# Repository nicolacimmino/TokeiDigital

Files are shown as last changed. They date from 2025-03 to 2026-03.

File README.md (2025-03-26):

# TokeiDigital

TokeiDigital [to̞ke̞ːdigital] is a line of clocks for geeks, nerds, and makers that come in a kit to assemble. The clock faces are unconventional and, true to the spirit of this project, always abound with colorful, blinking lights. These clocks are for you if:

* You believe a UART is a cool interface to setup a clock.
* You believe setting registers HEX values in a terminal is a good way to change LED colors and tweak settings.
* You believe a clock that just shows time with two hands is boring.



All models come with full schematics, PBCs, source code and all tools needed to program the clock. The project is OSHWA certified (PL000019).

Additionally you can buy them as kits ready to assemble on Tindie: https://www.tindie.com/stores/nicola_cimmino/

### Models

|Model|Description|Time|Date|DST|LEDs|Movement|
|-----|---|---|----|---|----|----|
| [TD-FBUH01](board/TD-FBUH01) |Reproduction of the iconic Berlin Uhr.|X||X*1|36 RGB|TD-M5037|
| [TD-FDCF01](board/TD-FDCF01) |60 LEDs display time encoded as DCF77 bitstream.|X|X|X|60 RGB|TD-M5037|

<sub>*1) How can DST work if there's no date? The movment, internally, tracks the date, but the clock face doesn't have LEDs to show it. For DST Auto to work correctly you will need to set the date using the serial interface.</sub>

### Movements

|Model|Description|UART|Backup<br>Battery|W (mm)|H (mm)|
|-----|---|---|----|---|----|
| [TD-M5037](board/TD-M5037)|Basic but powerful movement.|X|CR2032|50|37|

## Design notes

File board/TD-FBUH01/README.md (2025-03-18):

## TD-FBUH01

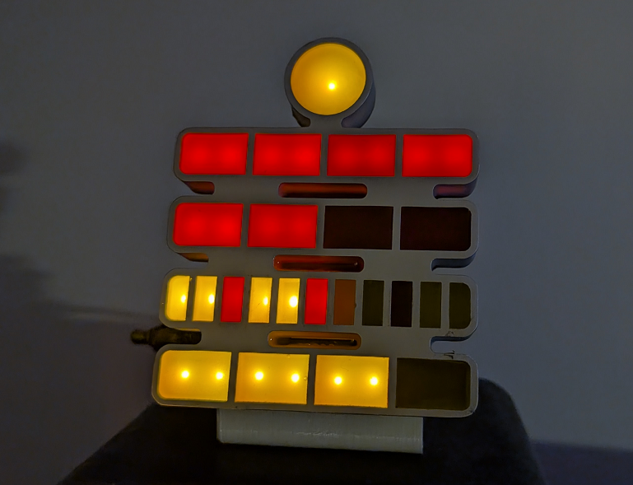
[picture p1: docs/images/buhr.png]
BerlinUhr


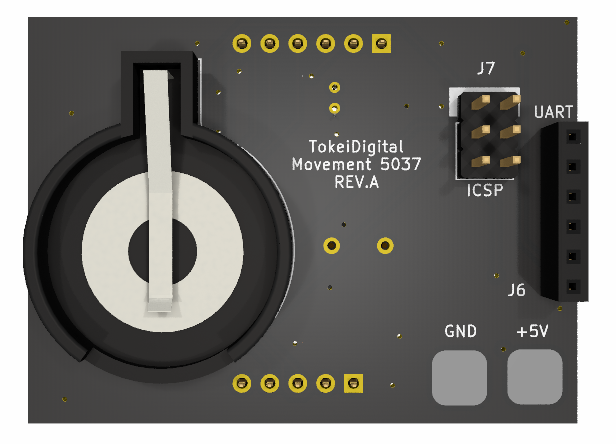
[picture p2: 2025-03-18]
docs/images/TD-M5037-pinout-back.png

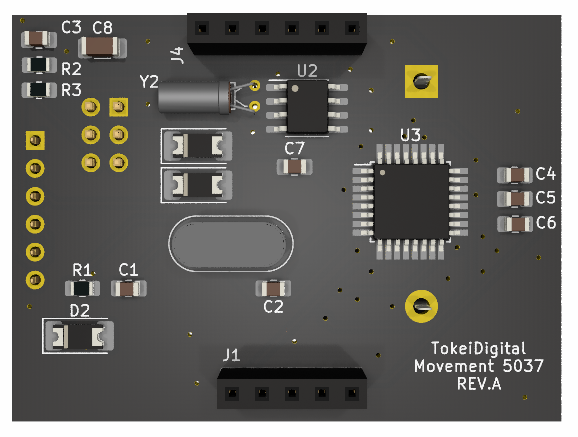
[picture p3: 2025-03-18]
docs/images/TD-M5037-pinout.png

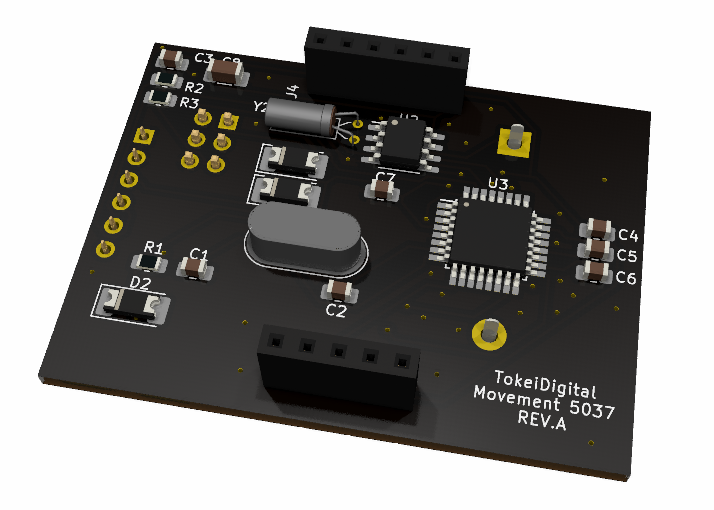
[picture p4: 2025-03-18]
docs/images/TD-M5037.png

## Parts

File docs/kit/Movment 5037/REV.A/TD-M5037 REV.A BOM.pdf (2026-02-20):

## Movement 5037 - REV.A BOM

Reference | Qty | Value
BT1 | 1 | CR3032 Holder
C1, C2 | 2 | 22p (0805)
C3, C4, C5, C6, C7 | 5 | 100nF (0805)
C8 | 1 | 10uF (1206)
D1, D2, D3 | 3 | 1N5817 (2010)
J1 | 1 | Pin 1x5 Vertical Female
J4, J6 | 2 | Pin 1x6 Vertical Female
R1, R2, R3 | 3 | 10K (0805)
U2 | 1 | DS1307 (SOIC-8)
U3 | 1 | ATmega328PB-QFP
Y1 | 1 | 16MHz (TH)
Y2 | 1 | 32.768KHz (TH)

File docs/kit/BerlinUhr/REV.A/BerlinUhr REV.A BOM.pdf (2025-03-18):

## BerlinUhr - REV.A

Reference | Qty | Value
D1..D36 | 36 | WS2812 5mm
SW1, SW2, SW3 | 3 | SW_Push
J1 | 1 | Pin 1x5 Vertical Female
J2 | 1 | Pin 1x6 Vertical Female

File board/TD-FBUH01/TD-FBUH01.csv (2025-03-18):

# | Reference | Qty | Value | Footprint | DNP
1 | D1, D2, D3, D4, D5, D6, D7, D8, D9, D10, D11, D12, D13, D14, D15, D16, D17, D18, D19, D20, D21, D22, D23, D24, D25, D26, D27, D28, D29, D30, D31, D32, D33, D34, D35, D36 | 36 | ~ | ClockIt:WS2812-5MM
2 | SW1, SW2, SW3 | 3 | SW_Push | ClockIt:Tactile SW SMD
3 | U1 | 1 | ~ | ClockIt:Movement5037 TH

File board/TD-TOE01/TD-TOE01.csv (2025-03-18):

# | Reference | Qty | Value | Footprint | DNP
1 | BT1 | 1 | CR3032 Holder | ClockIt:CR2032 Holder
2 | C1, C2 | 2 | 22p | ClockIt:C_0805
3 | C3, C4, C5, C6, C7 | 5 | 100nF | ClockIt:C_0805
4 | C8 | 1 | 10uF | ClockIt:C_1206
5 | D1, D2, D3 | 3 | 1N5817 | ClockIt:D_2010
6 | J1 | 1 | Pin 1x5 | ClockIt:PIN 1x05
7 | J4, J6 | 2 | Pin 1x6 | ClockIt:PIN 1x06
8 | J5, J8 | 2 | PowerPad | ClockIt:Power Pin
9 | J7 | 1 | AVR-ISP | ClockIt:PIN 2x03
10 | R1, R2, R3 | 3 | 10K | ClockIt:R_0805
11 | U2 | 1 | DS1307 | ClockIt:SOIC-8
12 | U3 | 1 | ATmega328PB-QFP | ClockIt:TQFP-32
13 | Y1 | 1 | 16MHz | ClockIt:Crystal Vertical
14 | Y2 | 1 | 32.768KHz | ClockIt:Crystal Horizontal

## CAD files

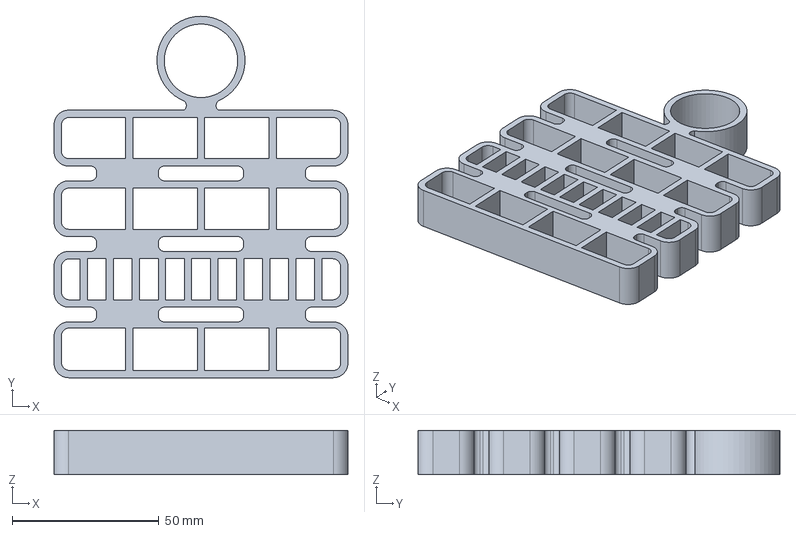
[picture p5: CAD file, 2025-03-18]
3d/TD-FBUH01/TD-FBUH01.FCStd
100.0 x 123.0 x 15.0 mm

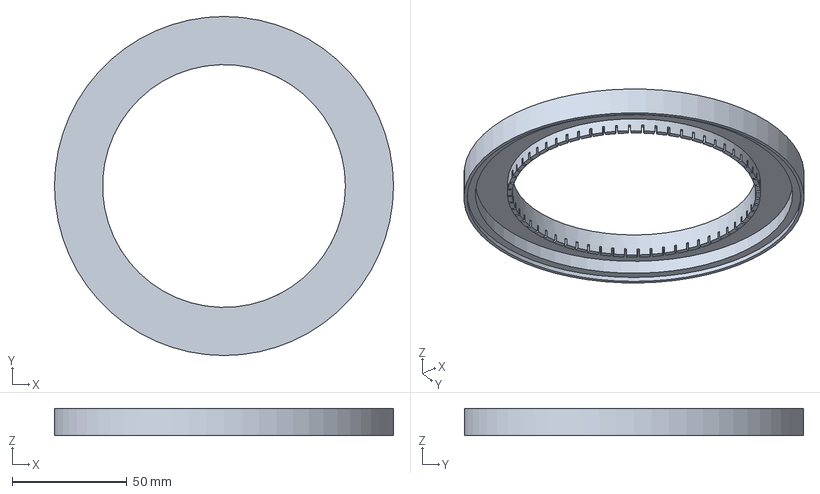
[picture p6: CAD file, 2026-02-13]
3d/TD-FDCF01/FaceDCF77_v3.FCStd
148.0 x 148.0 x 12.0 mm

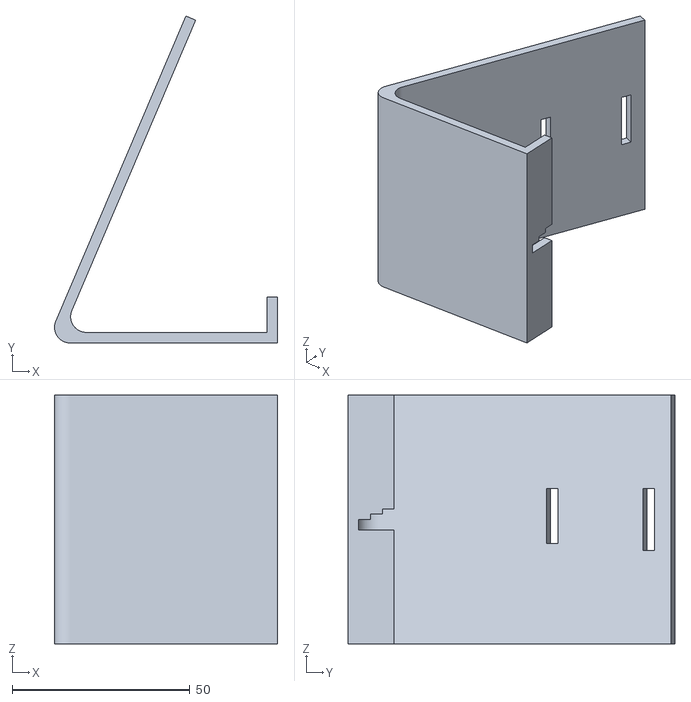
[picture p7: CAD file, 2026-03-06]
3d/TD-M5037A-SM/TD-M5037A-SM-Body.stl
62.7 x 92.0 x 70.0

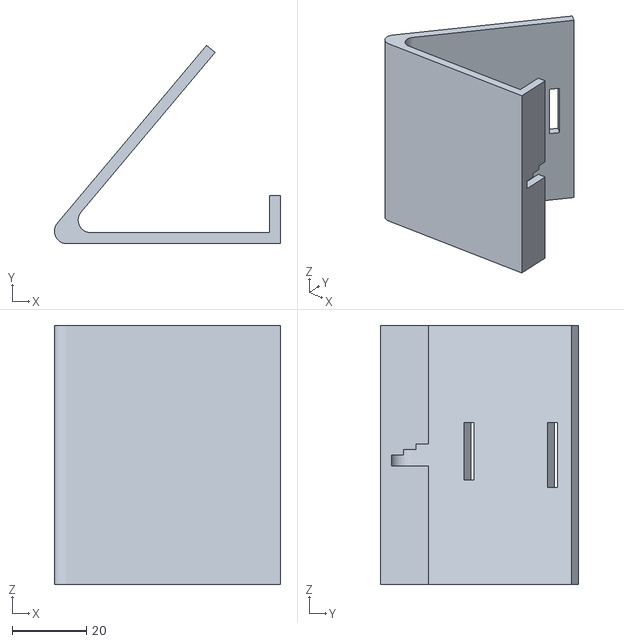
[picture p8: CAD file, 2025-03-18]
3d/TD-M5037A-SS/TD-M5037A-SS-Body.stl
61.1 x 53.6 x 70.0

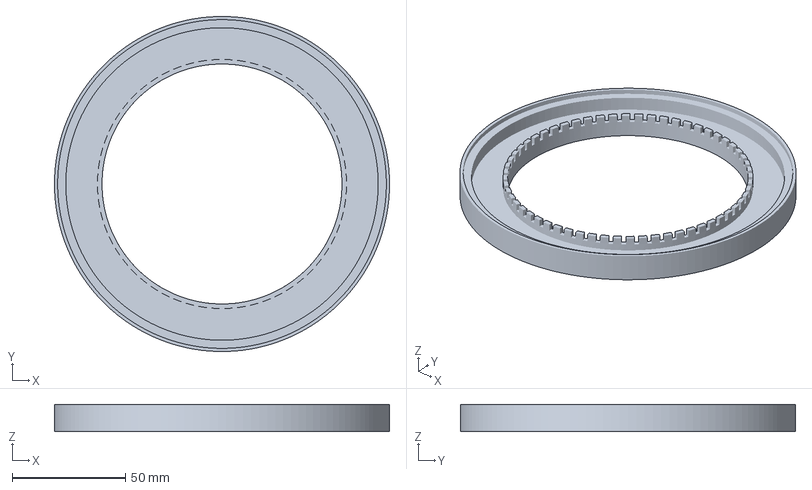
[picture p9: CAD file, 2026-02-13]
3d/TD-FDCF01/FaceDCF77_v3-Body.3mf
148.0 x 148.0 x 12.0 mm

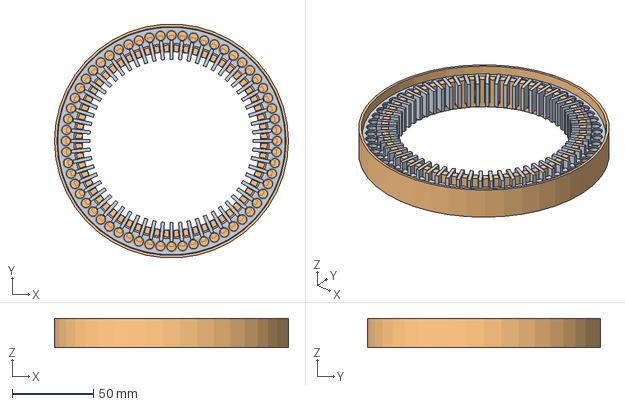
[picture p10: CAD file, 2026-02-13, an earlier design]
3d/TD-FDCF01/FaceDCF77_v2.FCStd
144.0 x 143.6 x 18.0 mm
LightGuide
Cover

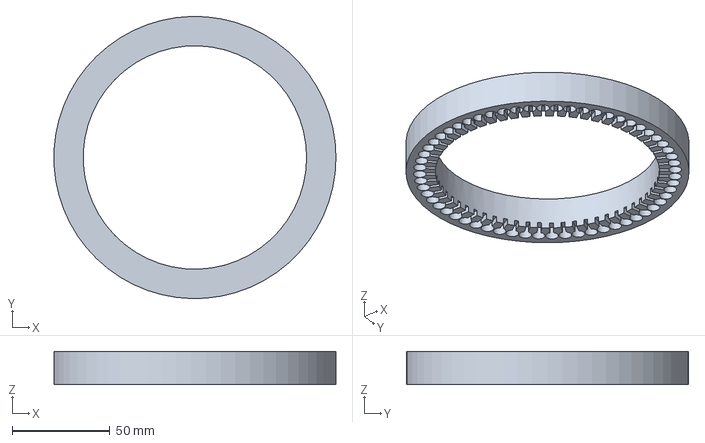
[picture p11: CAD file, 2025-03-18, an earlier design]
3d/TD-FDCF01/FaceDCF77.FCStd
143.9 x 143.9 x 17.0 mm

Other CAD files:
3d/TD-M5037A-SM/TD-M5037A-SM.FCStd
3d/TD-M5037A-SS/TD-M5037A-SS.FCStd
3d/TD-FDCF01/FaceDCF77_v3-Body.stl

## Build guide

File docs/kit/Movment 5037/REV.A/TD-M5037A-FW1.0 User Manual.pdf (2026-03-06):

# TD-M5037A-FW1.0

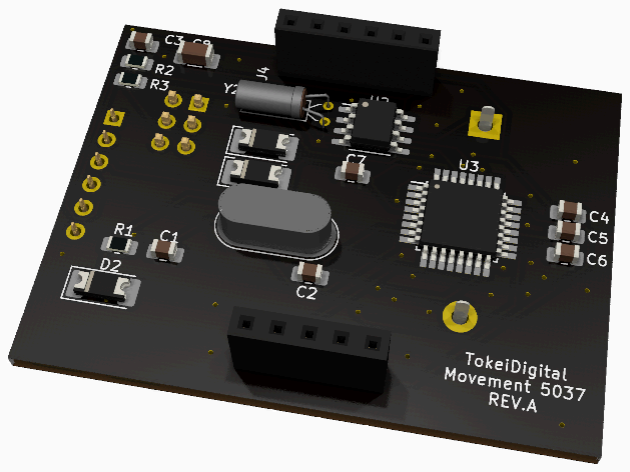
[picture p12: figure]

# User Manual

TD-M5037A-FW1.0 User Manual

# General

## Features

The Tokei Digital TD-M5037 is a general purpose clock module that can be used as the base for designing clocks with different faces. It provides a RTC, with a backup battery, that can keep track of the current date and time even when the clock is not powered.

The module has a UART interface, allowing the user to set the time via a command interface and to tweak the configuration of both the module and the clock face.

Additionally the module provides several GPIO pins to both control a clock face and receive input from buttons placed on the clock face. These buttons allow the user to set the time in a more traditional way.

The module can also automatically switch to DST and back (EU rules only in FW1.0, for other territories DST can be set manually through the UART or simply ignored and time adjusted manually on the change date).

If you purchased the TD-M5037A as a kit to assemble see the “Assembling the Board” chapter for assembly instructions.

## Connections

Two female pin headers, protruding on the top side (opposite the battery) provide the mating interface to the clock face. The headers have 5 and 6 pins respectively to serve as a guide for the correct orientation of the module when plugging it on the face. These pins provide power to the clock face, digital data to control it, and bring into the module the lines from the three A,B,C buttons.

The choice to have the buttons on the clock face instead of the module was made to provide more flexibility in the design of the final clock, leaving freedom on the placement of the buttons on the face. In the same way, the power input to this module is made of two large pads where to solder the power supply. This allows for greater flexibility in the placement of eventual battery holders or external power connectors. An onboard USB connector would have instead limited the options and, depending on the clock face shape and orientation, could have resulted in the USB connector sitting in a non suitable location.

On the side opposite the headers is a holder for a CR2032 battery. If the battery is not installed time will be lost every time the power is lost. It’s strongly recommended to use a backup battery, however normal operation is possible without.

On the same side is also an ICSP (In Circuit Serial Programmer) interface that allows to flash a new version of the firmware or to flash an Arduino bootloader. If you received the module as part of a clock kit the firmware has already been flashed with the correct one for the face you selected and you will not need this interface.

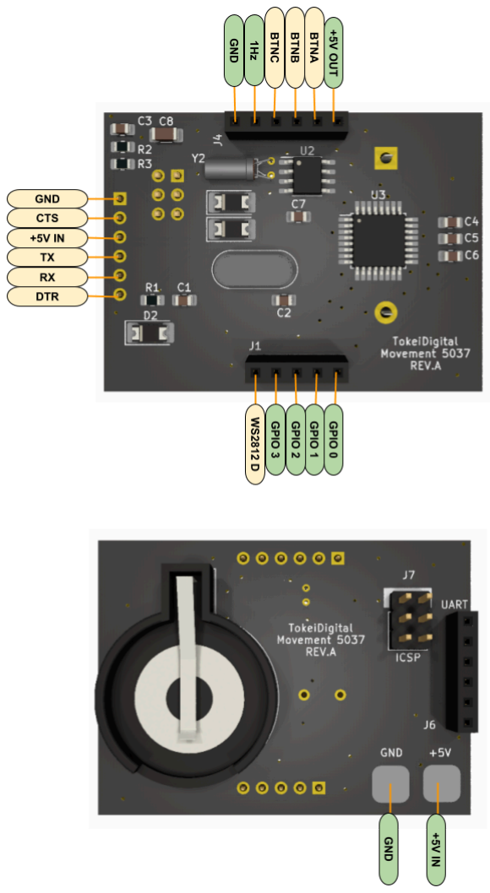
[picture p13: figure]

The table below details all the pins and their function.

+5V OUT | Power supply output for the clock face. Max available current for the face is 100mA.
BTNA,B,C | Input pins for Buttons A,B,C. The module has internal pull-ups and expects the buttons to be pulling towards ground when pressed. These buttons allow you to do things like setting the date/time.
1Hz | 1Hz Square Wave output. This is an open collector output.
GND | Common ground connection for powering the clock face.
CTS/TX/RX/DTR | UART interface. Allows to configure the clock through a serial interface. Also, if the module is flashed with the Arduino bootloader, sketches can be uploaded through this interface.
GPIO0,1,2,3 | General input/output pins that can be used by the clock face.
WS2812D | Dedicated output pin for clocks using WS2812 LEDs. If your clock face doesn’t use such LEDs this pin can be used as general IO.
+5V IN | Power Supply pad. There is polarity protection on board but no voltage protection. Ensure your power supply is stable and doesn’t exceed 5V. It needs to be able to supply enough current for the clock face (the movement consumption is few mA only).

## Setting Date and Time

Time set mode is entered with a long press on the A button. The first settable value (usually the hours) will start to flash on the clock face. Usually the clock will also indicate in some other way that it entered the time set mode, for instance flashing an LED or changing its color. For details see your specific clock face user manual.

NOTE: depending on how your clock displays time, if the current value being set is zero you might not see anything flashing (e.g. in a binary clock). Press B or C once so the value is increased/decreased.

Once time set mode is entered use B and C to increase/decrease the value being set respectively. To move to the next value (e.g. minutes) just press once A. Depending on the abilities of your clock, you will cycle through all the values that can be set and return to the hours.

Once you are done setting the time, long press again A to exit time set mode.

Hint: to achieve a second-accurate setting, set the clock to the next minute. Then wait in time set mode until your reference clock shows :59 seconds, only at this point long press on A to exit time set mode. This works because, upon exciting time set mode, the clock always starts from second :00.

## Display Test Mode

It’s possible to enter test mode for your clock by long pressing on the C button. In this mode your clock will light all LEDs regardless of current time. This can be useful to ensure all LEDs are functioning and to test your power supply and ensure it can provide enough current. Long press again C to exit test mode.

# Assembling the Board

## Packing List

Before proceeding with the assembly of the components on the board, double check the packing list to make sure you have received all components and that everything is in good order.

Bag | Content
A | 2 x 22p (0805)
B | 5 x 100nF (0805)
C | 1 x 10uF (1206)
D | 1 x 1N5817 (2010)
E | 3 x 10K (0805)
F | 1 x ATmega328 (QFP-32) 1 x DS1307 (SOIC-8)
G | 1 x 16MHz Crystal 1 x 32.768KHz Crystal 1 x CR3032 Holder 1 x Pin 1x5 Vertical Female 1 x Pin 1x6 Vertical Female
| 1 x PCB TD-M5037A REV.A

## Top Assembly

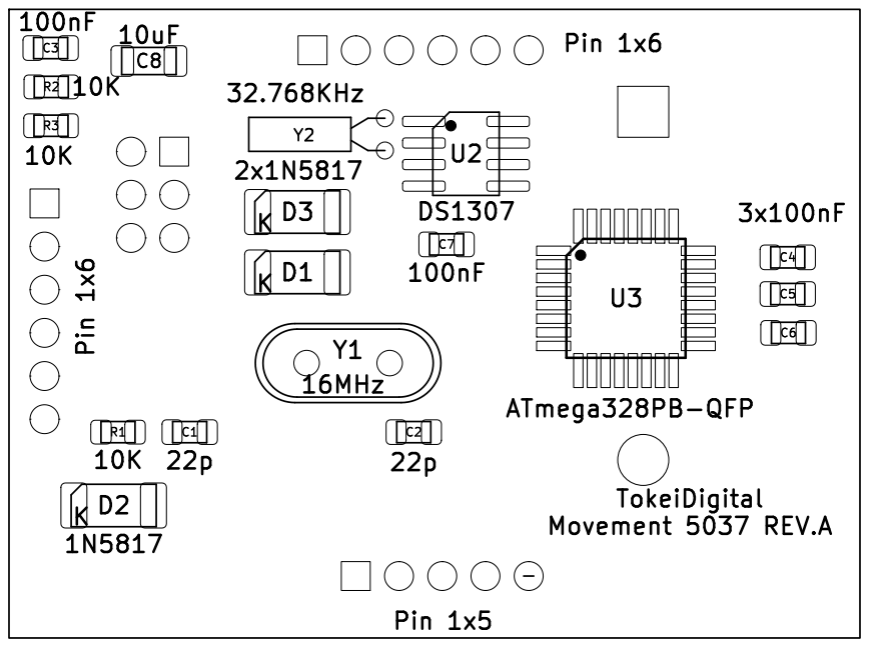
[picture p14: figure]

All components, with the exception of the battery holder, are assembled on the top part of the board. Depending on the tools you have available and your preference, you can use solder paste and position all the SMDs first to then reflow the board or just assemble the SMDs by hand. If you choose to assemble by hand make sure you have a very fine solder tip and very fine (0.2mm) tin. Pay attention to the orientation of diodes (the K marking on the image above corresponds to the grey band on the body of the component). Also the two chips need to be aligned with the dot on the body matching the image above. Assemble the crystals next and, finally, solder the pin headers on this same side of the board.

## Bottom Assembly

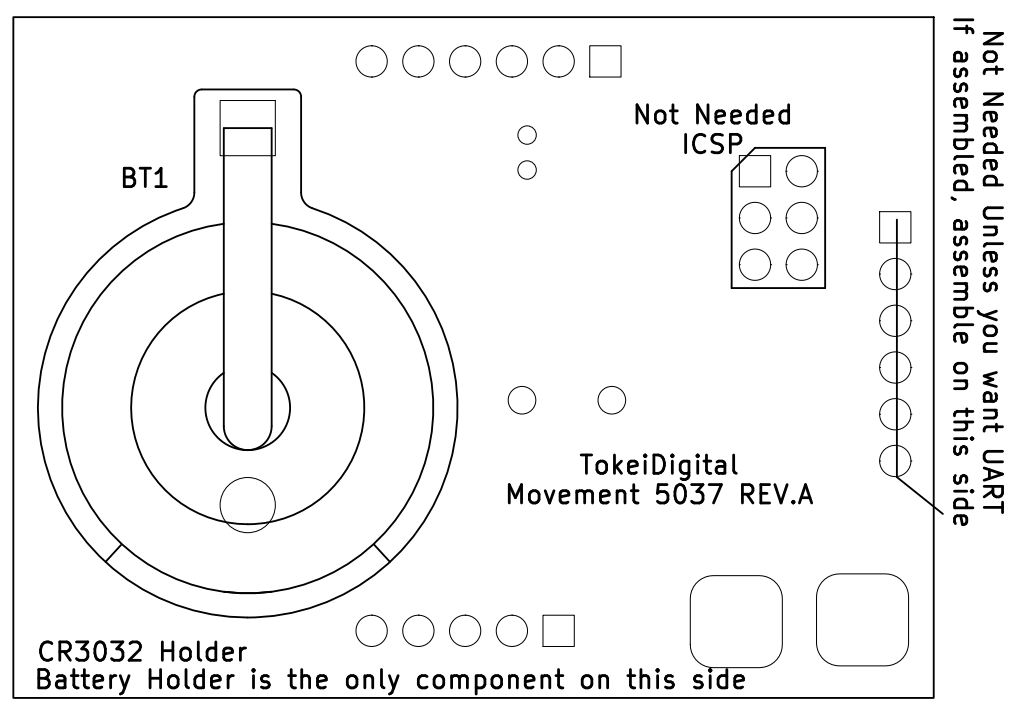
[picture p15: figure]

Flip the board and install the battery holder. For clock operation no other components are needed. If you are planning to use the UART you can install a 6 pin header on the pads labelled UART on the board. The choice of the type of pin header (male/female, 90 degrees etc.) depends on the type of USB-UART adapter board you have, whether you plan to encase the clock or not. The square pin is GND.

Also the ICSP connector (2x3 pins) is not needed unless you want to replace the firmware of the module, for instance to flash your own code for the clock face, an Arduino bootloader or an updated version of the firmware. Again, the type of pins depends on your programmer cable, though usually these are male pins.

Finally a power source needs to be soldered to the GND and +5 pads. Once more, the type of cable, battery holder or perhaps USB connector adapter board depends on how you plan to display and eventually encase your clock. For this reason the board was not designed with a USB onboard connector but just with the pads.

# Advanced

## UART

The module exposes a UART interface that allows the user to configure the module, including setting time, DST and, depending on the clock face, color of the LEDs and other face features.

## Physical Interface

The only pins needed to control the UART are TX, RX, and GND. The other standard serial port lines are used only by the Arduino bootloader if you choose to flash it.

The UART operates at 9600 BAUD, 8 bits, 1 stop bit (no parity).

The terminal should be configured for CR+LF line ending.

## Commands

Press enter once you connect to get a list of all the available commands and a banner reporting the current hardware and firmware versions. If you don’t receive any response, double check the connections and make sure the serial port parameters are set correctly.

TOKEI DIGITAL MOVEMENT 5037
VER: V1.0
FACE DRIVER: BUHR
H | HELP
N | PRINT NOW
R [START] [END] DUMP REGISTERS
S [START] | SET REGISTERS
T H:M WD D-M-Y | SET DATE/TIME
X | EXIT
OK

When you connect you might start to receive a burst of messages every second. These report the current date/time and other information. They can be set on/off by setting the relevant register (see next section). If the messages are coming they will stop once you press enter and will not resume until you exit interactive mode by giving the “X” command.

Print Current Time (N)
Send the “N” (now) command and press enter. The module will respond with the current date and time:

19:14 2 11-02-25
OK

The string is in the format:

HH:MM dayOfWeek day-month-year

Day of week is 1-7, with 1 indicating Monday.

Set Current Time (T)
Send the “T” (time) command followed by a space and the date and time you want to set. Use the same format returned by the N command.

T 19:14 2 11-02-25
OK

Dump Registers (R)
Send the “R” (read registers) command and press enter. The module will respond with a dump of all registers. Optionally you can specify a start and end (hex values) to limit the output.

R 0B 14
0008 | 00.00.00.00.00
0010 00.00.00.00.00.
OK

R
0000 00.00.00.01.00.00.00.00 0008 00.00.00.00.00.00.00.00 0010 00.00.00.00.00.00.00.00 0018 00.00.00.00.00.00.00.00 0020 00.00.00.00.00.00.00.00 0028 00.00.00.00.00.00.00.00 0030 00.00.00.00.00.00.00.00 0038 00.00.00.00.00.00.00.00 0040 00.00.00.05.00.00.05.05 0048 00.04.02.00.00.00.05.05 0050 00.05.02.04.04.01.06.02 0058 01.05.00.02.02.02.30.30 0060 30.00.00.00.00.00.00.00 0068 00.00.00.00.00.00.00.00 0070 00.00.00.00.00.00.00.00
0078 00.00.00.00.00.00.00.00
OK

For the meaning of each register see the next section which details the movement registers. See also your clock guide for face specific registers.

Set Registers (S)
Send the “S” (set registers) command followed by a space and the address (hexadecimal) of the first register you want to set. This command is interactive and will print the address and current value of the register.
You can now enter a new value, in hexadecimal and press enter. If you don’t want to change that register value you can just press enter to move to the next. Once you are done editing press X and enter to exit the command.

S 7B
007B 00 .
007C 01 .01
007D 02 .02
007E 00 .X
OK

Exit Interactive Mode (X)
Once you are done you can send the X command and press enter to exit the interactive mode. If the serial output is enabled (see register 0x03) the notifications will resume.

## Registers Map

0x00 - 0x3F Movement Registers | 0x00 | DST. | 0=AUTO, 1=OFF, 2=ON
| 0x01 | Reserved for future use.
| 0x02 | Reserved for future use.
| 0x03 | Serial output protocol. | 0=OFF, 1=V1
0x40 - 0x7F Face Registers | See face manual for usage.

0x00 If set to 0 DST AUTO is enabled and the clock will transition automatically in and out of summer time on the correct date. Currently the module supports the EU rules only. If you live in a different territory you can set manually DST on/off on the change date and the time will adjust. You can also leave DST OFF and change the time manually on the change day.

0x03 Controls the serial output protocol. When enabled (set to 1 for Version 1) the module will send out messages at one second interval. The messages continue indefinitely until you press enter, at that point they stop to allow usage of the interactive interface. The messages will resume exiting interactive mode with the X command. Messages look as follows:

$V1!INFO0,V1.0,DCF77
$V1!DATE,11-02-2025
$V1!TIME,19:37:29
$V1!DOW,2
$V1!DST,OFF,AUTO

Each message starts with $ followed by the protocol version. Following are comma separated tokens. The first indicating the message type and the others, in variable amount, are the parameters. Each message ends with a CR+LF.

$V1!INFO0 reports firmware version and face type.

$V1!DATE reports the current date in dd-mm-yyyy format.

$V1!TIME reports the current time in HH:MM:SS format.

$V1!DOW reports the current day of week. The value ranges from 1 to 7. Monday being 1.

$V1!DST reports the current DST status. The first parameter is either ON or OFF. The second parameter is present only if AUTO is enabled.

## Flashing the Arduino Bootloader

Whether you purchased the module on its own to design your own face, or you received it as part of a clock kit and you want to write your own firmware for it, you have the option to flash the Arduino bootloader on the board and use Arduino sketches.

NOTE: if you flash the Arduino bootloader it will override the clock firmware. For your clock to work you will need to write a sketch for it. Tokei Digital doesn’t provide Arduino sketches for its clocks. However you can also flash back the correct firmware, see next section for details.

If you are sure you want to flash the Arduino bootloader follow these simple steps:

- Connect an ICSP programmer (such as USPAsp) to the ICSP connector
- Open the Arduino IDE and configure the board as seen below (1). It’s important you choose ATMega328P 5V, 16MHz or things won’t work correctly.

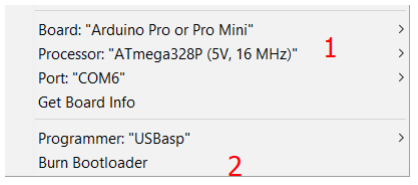
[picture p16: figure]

- Choose “Burn Bootloader” (2)
- Once the process ends disconnect the programmer
- Connect now the board with a USB UART as any other Arduino board
- Select the right COM port that gets assigned to your board
- Upload your first sketch!

Note: REV.A of the board has a 100nF capacitor labelled C4 that interferes with the reset circuitry of the Arduino (which uses the serial interface DTR line to reset the processor). Remove this capacitor if you want to flash the Arduino bootloader. Future revisions of the board will omit this component as, in fact, it’s not needed even in other configurations.

## Flashing the Firmware

If you purchased the module as part of a clock kit you do not need to flash the firmware as the ATMega was already flashed for you with the FW variant needed for your clock face. However, if you are planning to flash your own firmware, or restore the original one after flashing the Arduino bootloader follow these simple steps.
This assumes you have a USBAsp ICSP programmer and a working installation of avr-gcc.
- Connect the board to the ICSP programmer
- Clone the https://github.com/nicolacimmino/TokeiDigital repository
- Open a unix like shell (e.g. GitBash) or your terminal if you are running linux
- Run the interactive flash tool you can find under src/movement with sh flash.sh
- You will be presented with a dialog like below:

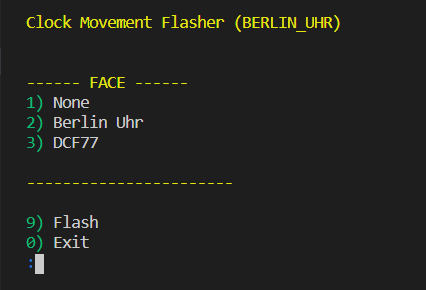
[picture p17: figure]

- Select the correct face and then press 9 to flash

If you have a different programmer have a look into the Makefile in the src/movement folder of the repo and adjust for your programmer.

# Appendix A - HW Revisions

REV.A | First version. The only known issue at the time of writing is C4 interfering with Arduino reset. You can safely remove C4.

# Appendix B - Schematic

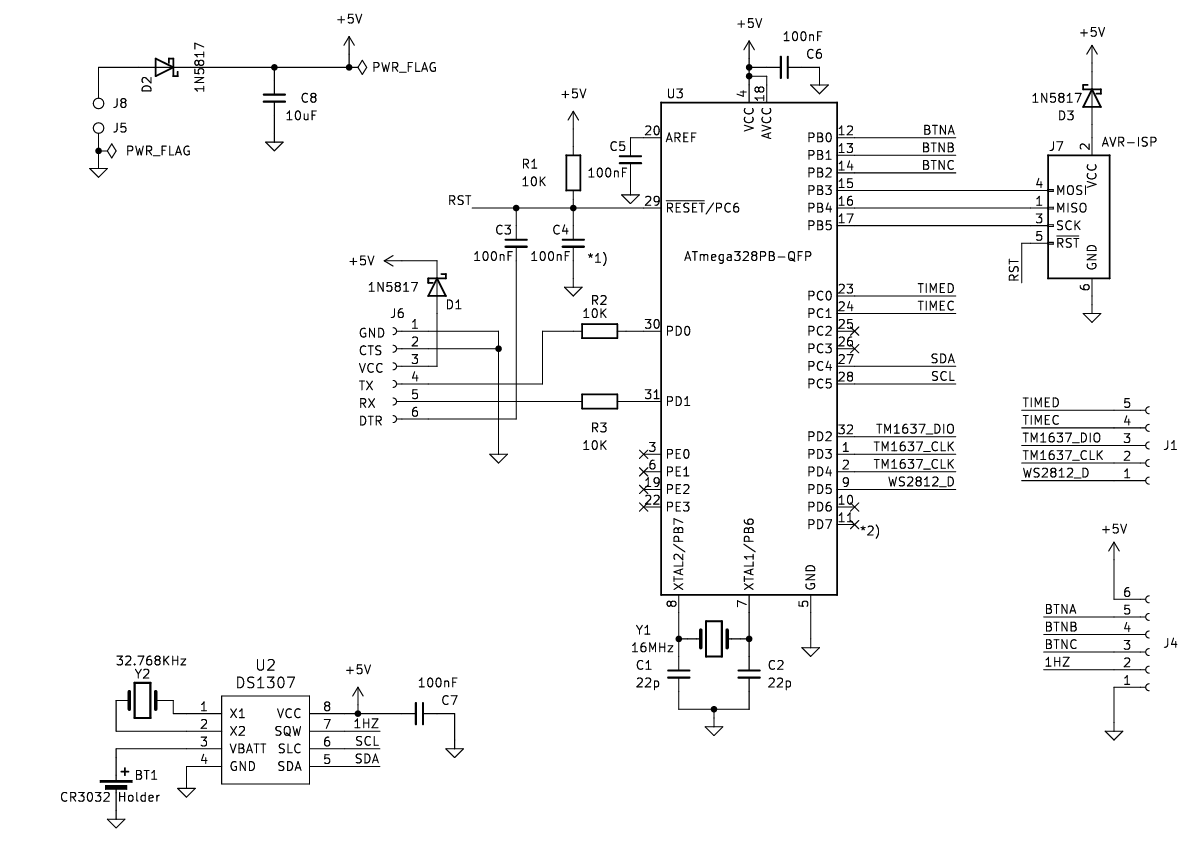
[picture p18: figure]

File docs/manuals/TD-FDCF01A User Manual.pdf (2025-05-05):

# TD-FDCF01A

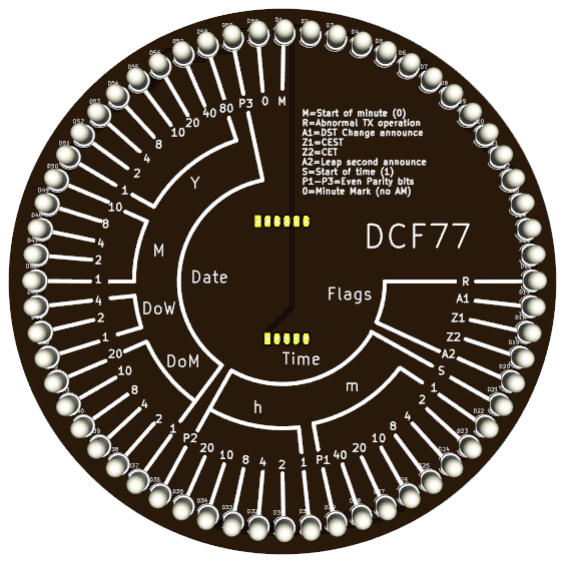
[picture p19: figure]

# User Manual

TD-FDCF01A User Manual

Page 2/21

TD-FDCF01A User Manual

Page 3/21

TD-FDCF01A User Manual

Page 4/21

TD-FDCF01A User Manual

# General

## Features

The TD-FDCF01A is a clock showing time with 60 RGB LEDs that represent the bitstream of a DCF77 time signal. The clock can display the current time, in 24h format, the full date, and indicator flags showing summer/winter time being in use or being about to change. Thanks to clear markings on the silkscreen for each LED, it’s possible to easily read the time, at a glance, provided you know what you are looking at of course. This can be done without the need to memorize the bits position or refer to the manual.

The TD-M5037 movement gives this clock the ability to keep track of time even when the main power is removed. Additionally, the movement can automatically switch from/to DST (EU rules only), manual switchover is also possible, see TD-M5037 User Manual for all details.

NOTE: this is NOT a radio controlled clock. Time and date need to be set manually.

Page 5/21

TD-FDCF01A User Manual

## About the DCF77 Signal

The DCF77 is a time station, located near Frankfurt, that broadcasts a signal encoded with a bitstream representing the current time, date, and some additional information. The signal can be received all over Europe and is used by clocks to date and time sync automatically.
A DCF77 bit stream consists of 60 bits that are encoded on the transmitted carrier by reducing the power of the carrier for 100 or 200 mS at the start of each second. The duration of the power reduction signals a zero (100mS) or a one (200mS). Below is an explanation of the meaning of each bit.

Bit 0
Minute start. This bit is always zero.

Bit 1-14
German “Federal Office of Civil protection and Disaster Relief” Civil warnings. Additionally these same bits encode the current weather in several cities around Europe. The weather info is broadcast for a different city every minute and is encrypted. NOTE: because TD-FDCF01A does NOT receive a DCF signal these bits bear no real-world meaning and on the face they are generally off (save for the “seconds hand” going around or other effects the user might configure or program).
These bits CANNOT be used to determine the weather or civil alerts in this clock face.

Bit 15
“R” bit, if set, indicates an abnormal operation of the transmitter.

Bit 16
“A1” Summer time/Standard time change warning. Set one hour before a change in/out of DST occurs.

Page 6/21

TD-FDCF01A User Manual
Bit 17
“Z1” Set when CEST is in use (Summer Time).

Bit 18
“Z2” Set when CET is in use (Standard Time).

Bit 19
“A2” Set during the hour before a leap second. Note: current firmware implementation doesn’t calculate this bit.

Bit 20
Start of time, this bit is always set.

Bit 21-27
Current time minutes. Starting from Bit 21 each one has the following weight: 1,2,4,8,10,20,40 minutes. So, for instance, if Bit 21 and 27 are set the minutes are 1+40=41.

Bit 28
Minutes parity bit. This bit is an even parity bit over the bits 21-27. In other words, it’s set or clear so that the amount of bits set in the whole 21-28 range is even. For instance consider this sequence:
Bit 21 | Bit 22 | Bit 23 | Bit 24 | Bit 25 | Bit 26 | Bit 27 | Bit 28
1 | 0 | 0 | 0 | 0 | 1 | 1 | 1

Page 7/21

TD-FDCF01A User Manual

Bits 21-27 have a total of 3 bits set, for this reason bit 28 is set so that the total amount of bits set is an even number (4). Conversely in this sequence:

Bit 21 | Bit 22 | Bit 23 | Bit 24 | Bit 25 | Bit 26 | Bit 27 | Bit 28
1 | 0 | 0 | 0 | 0 | 1 | 0 | 0

Bits 21-27 have a total of 2 bits set, for this reason bit 28 is not set as the amount of set bits is already an even number.

Bit 29-34
Current time hours. Starting from Bit 29 each one has the following weight: 1,2,4,8,10,20 hours. So, for instance, if Bit 29 and 35 are set the hours are 1+20=21.

Bit 35
Hours parity bit. This bit is an even parity bit over the bits 29-34. In other words, it’s set or clear so that the amount of bits set in the whole 29-35 range is even. This works on the exact same principle as the minute bits.

Bit 36-41
Current day of the month. Starting from Bit 36 each one has the following weight: 1,2,4,8,10,20. So, for instance, if Bit 36 and 37 are set the day of the month is 1+2=3.

Page 8/21

TD-FDCF01A User Manual
Bit 42-44
Current day of the week, with 1 being Monday and 7 Sunday. Starting from Bit 42 each one has the following weight: 1,2,4. So, for instance, if Bit 42 and 43 are set the day of the week is 1+2=3 which is Wednesday.

Bit 45-49
Current month with 1 being January and 12 December. Starting from Bit 45 each one has the following weight: 1,2,4,8,10. So, for instance, if Bit 45 and 46 are set the month is 1+2=3 which is March.

Bit 50-57
Current year in the century (0-99). Starting from Bit 50 each one has the following weight: 1,2,4,8,10,20,40,80. So, for instance, if Bit 50,52 and 55 are set the year is 1+4+20=25, so 2025.

Bit 58
Date parity bit. This bit is an even parity bit over the bits 36-57. In other words, it’s set or clear so that the amount of bits set in the whole 36-58 range is even. This works on the exact same principle as the minute and hours bits.

Bit 59
Minute Marker. This is the only bit in the whole stream that is never modulated, which means the amplitude is constantly 100% (neither a zero nor a one). This is used by the receivers to detect the beginning of the stream as the next bit.

Page 9/21

TD-FDCF01A User Manual

Page 10/21

TD-FDCF01A User Manual

## Reading Time

With the information above you should be able to read the date and the time from the clock face. Below is an example that we will use to clarify how the clock is read.

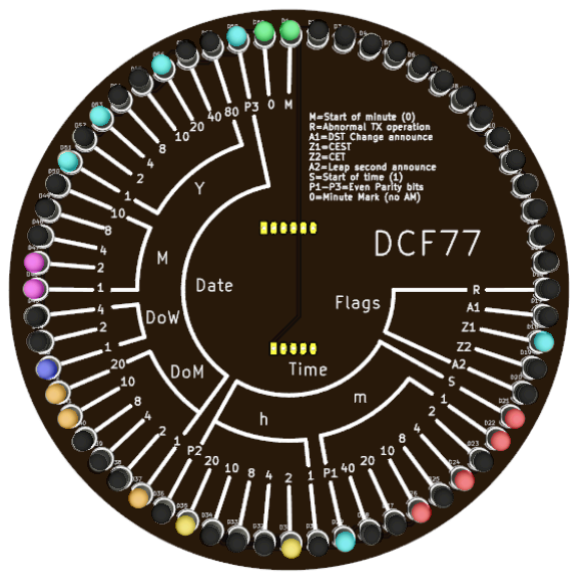
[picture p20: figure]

If you like the challenge, write down the date and time you can read before moving on to the next page.

Page 11/21

TD-FDCF01A User Manual

Starting from the zero position the first LED we find lit is the Z1 indicator. As seen also on the PCB silkscreen, Z1 indicates CEST is in use (Central European Summer time). Next is the S marker, this is the start of time and is always on, so we can ignore it.

Under the “m” (minute) bracket we have 3 LEDs lit, at positions 1,4 and 10. So, the minutes are 10+4+1=15. Note that P1 is also lit. This is because the “m” section has 3 LEDs on, so the parity P1 brings these to an even number (4).

Next are the hours, under the “h” bracket. Here we have 2 LEDs lit: 2 and 20, so the hours are 20+2=22. Note that P2 is off because the “h” section has already an even number of LEDs lit (2).

The following section, “DoM” is the day of the month. As above here 1,10,20 are lit so the day is 1+10+20=31.

Next is “DoW”, day of the week. With only 1 lit this is a Monday (Sunday is 7).

“M”, month is 2+1=3 so March

The year, “Y”, is 1+4+20=25 which, in the current century, is interpreted as 2025.

Finally, if you count all the LEDs set under the bracket “Date” they are 9. This is an odd number so P3 (which refers to the all set of bits in the date) is lit to make the total 10, an even number.

So, in summary, the face is showing: Monday, 31 March 2025 and time is 22:15. We also learn that we are on summer time.

Page 12/21

TD-FDCF01A User Manual

## Setting Time

Time set mode is entered with a long press on the A button. The first settable value (the hours) will start to flash on the clock face. Additionally the LED at zero position will glow steadily instead of flashing seconds.

NOTE: Upon entering time set mode you will not see any lights flashing if the current hours are “0”. Just press B or C to increase/decrease and you will see some values flashing.

Once time set mode is entered use B and C to increase/decrease the value being set respectively. To move to the next value (minutes) just press once A. Pressing again the A button will move you to the next settable value. Continue like this for the day, day of week (remember 1 is Monday and 7 is Sunday), month and year.

Once you are done setting the time, long press again A to exit time set mode.

Hint: to achieve a second-accurate setting, set the clock to the next minute. Then wait in time set mode until your reference clock shows :59 seconds, only at this point long press on A to exit time set mode. This works because, upon exciting time set mode, the clock always starts from second :00.

Page 13/21

TD-FDCF01A User Manual

## Display Test Mode

It’s possible to enter test mode by long pressing on the C button. In this mode your clock will light all LEDs regardless of current time. This can be useful to ensure all LEDs are functioning and to test your power supply and ensure it can provide enough current. Long press again C to exit test mode.

## Display Modes

The face supports 4 different colour palettes. Out of the box these are 3 different luminosity levels and, the 4th, is all LEDs off. The colour scheme can be changed by using the serial interface (see movement “Advanced” section for commands to set registers). A detailed memory map of the colour registers for this face can be found in the “Advanced” section of this manual.

During normal operation you can cycle through the modes by clicking the A button.

Page 14/21

TD-FDCF01A User Manual

# Assembling the Board

## Packing List

Before proceeding with the assembly of the components on the board, double check the packing list to make sure you have received all components and that everything is in good order.

Bag | Content
A | 60 x 5mm WS2812D LEDs
B | 1 x Pin 1x5 Vertical Male 1 x Pin 1x6 Vertical Male 3 x Tactile Push Buttons
| 1 x PCB TD-FDCF01A REV.A

Page 15/21

TD-FDCF01A User Manual

## Top Assembly

Insert all LEDs paying attention to orient the LED flat side as indicated by the silk screen. Ensure LEDs are all sitting at the same height. Notice how the LED pads are staggered (see picture below).

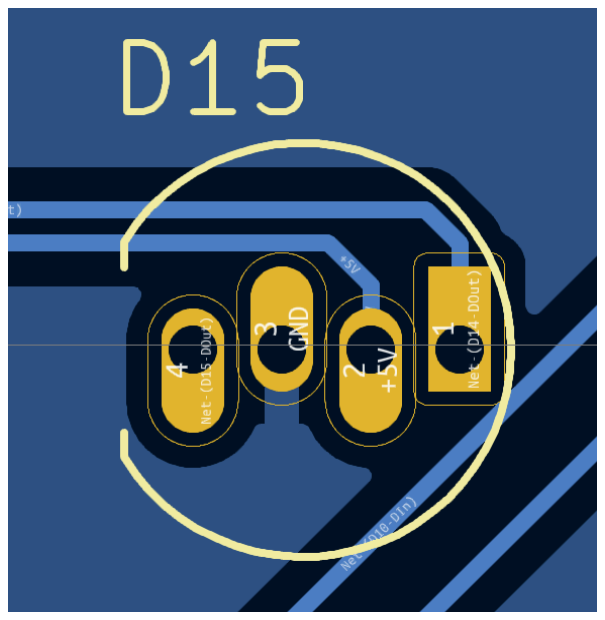
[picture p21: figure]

This facilitates manual soldering, given the relatively small clearance between the pads, it would otherwise be quite easy to create solder bridges. I found that the most convenient way to solder the LEDs is to put in a few and then solder first the square pins using a wider gauge tin (0.8mm worked very well for me). Next flip the board and make sure all LEDs are vertical, at the same height and generally well aligned. If something is off it’s very easy at this stage to rework it by just heating the single soldered pad holding them in place.

Page 16/21

TD-FDCF01A User Manual

Once happy with the alignment, solder the pins opposite the square ones using the same 0.8mm tin. When this is done, before doing the two middle pins, it helps to clip all the terminals close to the board. In this way it’s possible to solder the middle pins working from top, and not the side of the pin, minimizing the chances of a bridge forming. For this step it’s best to use a smaller gauge tin (for instance 0.2mm, but you might find other sizes working better depending on your solder tip).

## Bottom Assembly

Once all the LEDs are in place, you can add the pin strips that allow the movement to be plugged in. Make sure they are installed on the opposite side of the LEDs, as per silk screen.

You can finally then solder the 3 push buttons.

There are no other components on this PCB.

Page 17/21

TD-FDCF01A User Manual

## Testing

Power up the clock and enter test mode by long pressing the C button. This will cause all LEDs to light up ensuring everything is soldered correctly. You can exit test mode by long pressing on C again.

You can now set the time so you ensure all other buttons are working and the movement is operating as expected.

Both in Test Mode and in regular mode you can change the intensity of the LEDs by pressing on A, this will cycle through 3 levels and OFF screen mode.

Page 18/21

TD-FDCF01A User Manual

# Advanced

Your clock comes with a UART that you can use to send commands to it via a terminal program. This is not only an alternative way to set time, it’s also a way to change the clock colours. See the TD-M5037 User Manual for details on how to connect, send commands and alter register values.

## Registers Map

0x00 - 0x3F Movement Registers | See TD-M5037 User Manual for usage.
| 0x40 - 0x42 | Colour of OFF LEDs in R,G,B | Default is 0x000000 (black)
| 0x43 - 0x45 | Colour of Minutes LEDs in R,G,B | Default is 0x050000 (red)
| 0x46 - 0x48 | Colour of Hours LEDs in R,G,B | Default is 0x050500 (yellow)
| 0x49 - 0x4B | Colour of DoM LEDs in R,G,B | Default is 0x040200 (dark yellow)
| 0x4C - 0x4E | Colour of DoW LEDs in R,G,B | Default is 0x000005 (blue)
| 0x4F - 0x51 | Colour of Month LEDs in R,G,B | Default is 0x050005 (purple)

0x40 - 0x7F
Face Registers

Page 19/21

TD-FDCF01A User Manual
0x52 - 0x54 | Colour of Year LEDs in R,G,B | Default is 0x020404 (light blue)
0x55 - 0x57 | Colour of Flags LEDs in R,G,B | Default is 0x010602 (acqua)
0x58 - 0x5A | Colour of Markers LEDs (start of time, start of minute, minute marker) in R,G,B | Default is 0x010500 (green)
0x5B - 0x5D | Colour of Civil Warning Bits LEDs in R,G,B (currently unused, used only in test mode to show LEDs are working) | Default is 0x020202 (white)
0x5E - 0x60 | Colour of Seconds Hand LEDs in R,G,B Note: as the seconds’ hand moves around the clock it temporarily shadows the bit of the current second. You can disable the seconds’ hand by setting these registers to 0x000000. | Default is 0x303030 (bright white)
0x61 - 0x6F | Unused, colour table padding. | All 0x00
0x70 - 0x9F | Second color table, bytes meaning same as the first section above. This table can be activated by pressing A once. | Defaults to the same colours as the first table, but brighter.
0xA0 - 0xCF | Third color table, bytes meaning same as the first section above. This table can be activated by pressing A once more. | Defaults to the same colours as the first table, but even brighter.
0xD0 - 0xFF | Fourth color table, bytes meaning same as the first section above. This table can be activated by pressing A once more. | Defaults to all 0s (display OFF mode).

Page 20/21

TD-FDCF01A User Manual

# Appendix A - HW Revisions

REV.A | First version.

Page 21/21

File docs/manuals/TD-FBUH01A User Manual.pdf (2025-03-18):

# TD-FBUH01A

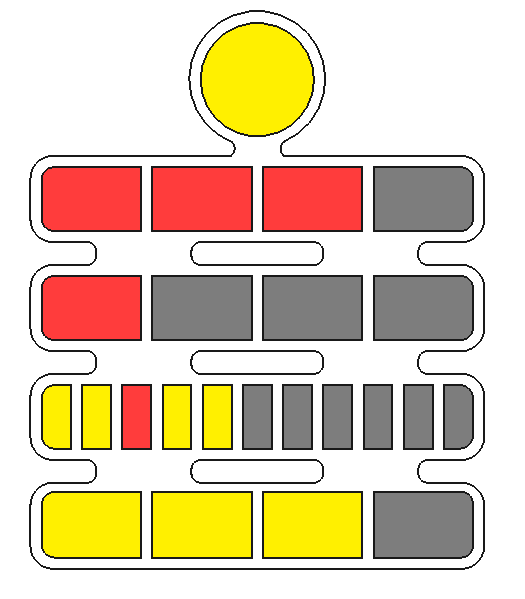
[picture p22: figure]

# User Manual

TD-FBUH01A User Manual

Page 2/21

TD-FBUH01A User Manual

Page 3/21

TD-FBUH01A User Manual

Page 4/21

TD-FBUH01A User Manual

# General

## Features

The TD-FBUH01A is a small scale replica of the iconic Berlin Uhr. The clock can display the current time, in 24h format, thanks to an ingenious set of coloured lights. The colours used in the original are red and yellow, and this is the default colour schema the face kit is shipped with. Thanks to its 36 RGB LEDs though, you can choose to personalize the clock to your liking.

The TD-M5037 movement gives this clock the ability to keep track of time even when the main power is removed. Additionally, the movement can automatically switch from/to DST (EU rules only), manual switchover is also possible, see TD-M5037 User Manual for all details.

## About the Berlin Uhr

The name translates literally to “Berlin Clock”. However, the real name of this timepiece is far less readable for the non German speakers as it originally was called Mengenlehreuhr. This less friendly name translates to “Set Theory Clock” and we will see soon why.

The unique time telling device was the only, when it was installed in June 1975, to show the time by means of coloured illuminated fields. At that time it sat on Uhlandstraße, in West Berlin. It’s since been relocated to Budapester Straße, on one side of the Europa Center shopping mall where it can still be admired in all its glory.

Page 5/21

TD-FBUH01A User Manual

## Reading Time

The “S” round light at the top blinks on and off signalling the seconds, it alternates one second on and one second off during normal operation. When the clock is in time set mode, this light will be steady and red.

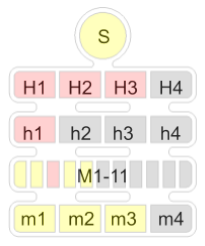
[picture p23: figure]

Hours are displayed in the two rows of red lights H1-H4 and h1-h4. Each of the H1-H4 lights is worth 5 hours, while each of the h1-h4 is worth 1 hour. This is not a positional system so, theoretically, any of the lamps could be in a given row, just their count matters. In practice though, the Berlin Uhr keeps things neat and lamps always start lighting from the left.
Page 6/21

TD-FBUH01A User Manual

In the example above we have 3 lit lights on the first row (3 X 5 = 15) and one in the second row. So the shown time hours are 15 + 1 = 16.

The other two rows indicate minutes and work exactly in the same way. M1-M11 lights are worth 5 minutes each, and m1-m4 1 minute each. So, the first row is 5 x 5 = 25 minutes, and the second 3 minutes for a total of 28 minutes.

If we put all this information together, we can tell the clock above shows 16:28.

There’s a peculiarity of row M1-M11: every 3rd light is red. This allows us to avoid counting all the lights, which might be tedious and error prone past the 30 min mark. We can instead count 15 for each red light lit and then just add 5 for each following yellow one. The larger spacing between two red lights on this row makes it quite fast to read minutes at a glance this way.

It should now be clear where the “Set Theory Clock” name comes from as each group of lights is a set of items with the same values (5 or 1).

Page 7/21

TD-FBUH01A User Manual

## Setting Time

Time set mode is entered with a long press on the A button. The first settable value (the hours) will start to flash on the clock face. Additionally the round light at the top will glow steadily in red.

NOTE: Upon entering time set mode you will not see any lights flashing if the current hours are “0”. Just press B or C to increase/decrease and you will see some values flashing.

Once time set mode is entered use B and C to increase/decrease the value being set respectively. To move to the next value (minutes) just press once A. Pressing again the A button will bring you back to hours.

Once you are done setting the time, long press again A to exit time set mode.

Hint: to achieve a second-accurate setting, set the clock to the next minute. Then wait in time set mode until your reference clock shows :59 seconds, only at this point long press on A to exit time set mode. This works because, upon exciting time set mode, the clock always starts from second :00.

## Display Test Mode

It’s possible to enter test mode by long pressing on the C button. In this mode your clock will light all LEDs regardless of current time. This can be useful to ensure all LEDs are functioning and to test your power supply and ensure it can provide enough current. Long press again C to exit test mode.

Page 8/21

TD-FBUH01A User Manual

# Assembling the Board

## Packing List

Before proceeding with the assembly of the components on the board, double check the packing list to make sure you have received all components and that everything is in good order.

Bag | Content
A | 36 x 5mm WS2812D LEDs
B | 1 x Pin 1x5 Vertical Male 1 x Pin 1x6 Vertical Male 3 x Tactile Push Buttons
| 1 x PCB TD-FBUH01A REV.A

Page 9/21

TD-FBUH01A User Manual

## Top Assembly

Insert all LEDs paying attention to orient the LED flat side as indicated by the silk screen. Ensure LEDs are all sitting at the same height. This will ensure a more consistent illumination of the different sections. Notice how the LED pads are staggered (see picture below).


This facilitates manual soldering, given the relatively small clearance between the pads, it would otherwise be quite easy to create solder bridges. I found that the most convenient way to solder the LEDs is to put in a whole row and then solder first the square pins using a wider gauge tin (0.8mm worked very well for me). Next flip the board and make sure all LEDs are vertical, at the same height and generally well aligned. If something is off it’s very easy at this stage to rework it by just heating the single soldered pad holding them in place.

Page 10/21

TD-FBUH01A User Manual

Once happy with the alignment, solder the pins opposite the square ones using the same 0.8mm tin. When this is done, before doing the two middle pins, it helps to clip all the terminals close to the board. In this way it’s possible to solder the middle pins working from top, and not the side of the pin, minimizing the chances of a bridge forming. For this step it’s best to use a smaller gauge tin (for instance 0.2mm, but you might find other sizes working better depending on your solder tip).

## Bottom Assembly

Once all the LEDs are in place, you can add the pin strips that allow the movement to be plugged in. Make sure they are installed on the opposite side of the LEDs, as per silk screen.

You can finally then solder the 3 push buttons.

There are no other components on this PCB.

Page 11/21

TD-FBUH01A User Manual

## Testing

Since you will be potting the LEDs in resin it’s a good idea to first ensure everything works fine. For this purpose the clock provides a test mode which lights up all the lights at the same time. To enter test mode just long press C for a couple of seconds. Test mode can be exited by long pressing C again or by power cycling the clock.

It’s strongly recommended to keep the clock powered in test mode when doing the resin pour, this way the lights will serve as a colour guide and prevent you pouring the wrong colour.

Page 12/21

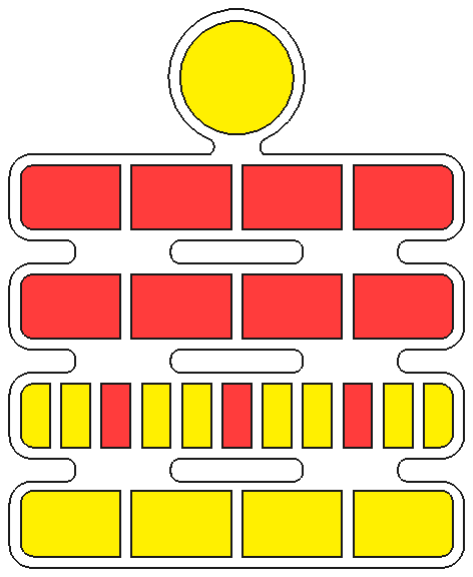
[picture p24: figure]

TD-FBUH01A User Manual

# Face Assembly

Once the electronics are good and tested it’s time to assemble the face plastic cover and do a resin pour to complete the clock. To complete this operation you will need the following materials that are not part of the kit:

- 2 part epoxy resin ready to mix
- Suitable resin dyes (white, yellow, and red for the classic look)
- Disposable plastic cups
- Disposable wooden or plastic sticks
- Large plastic syringe with no needle
- Working gloves to protect your hands when handling resin
- Paper towels and q-tips to clean spills
- Glue suitable for plastic

## Plastic Face

The first step is to glue the plastic face to the PCB, LEDs side. While using superglue is tempting, I suggest using a bit slower and weaker one as you might misalign the face and need to relocate it. Keep in mind that glueing at this stage serves only the purpose to keep things in place during the resin pour, so it doesn’t need to be extra strong.

Note: the plastic face has two recesses on one side, this is the side that should go towards the PCB as the recesses are meant to leave room for the pin headers solder bubbles.

Page 13/21

TD-FBUH01A User Manual

## Seal the wells

Before you can pour resin you should seal the wells into which the resin will be poured. Not only can resin leak in gaps between the PCB and the plastic, it can also make its way to the other side of the PCB through vias. I had good results pouring melted wax in the wells covering up to about half of the height of the LEDs and then letting it cool before proceeding. If some wax leaks through cracks it can be easily cleaned later without damaging the face. A long, straight candle, kept at an angle is a good source of a continuous stream of melted wax. You might also want to consider melting some wax in bain-maire, just pay extra attention not to burn yourself! Also, don’t pour all wax at the same time in all wells as that might overheat and warp the plastic.

## Resin

Note: before committing to a colour by actually doing a pour, consider if you want your clock with the standard red/yellow colour scheme, or you want to make it unique and use a different colour pair. Read the “Advanced” section to familiarize yourself with the serial interface through which you can change registers to achieve this and perhaps experiment with different colours. You can also choose to make the resin milky white, with no tint, so that you can change the colour scheme as you see fit for the day and mood.

For the resin pour I recommend mixing a 100g batch of resin. You will have some left at the end, but you will have peace of mind in case of small spills and you will be able to work more comfortably. If you want to keep it lean and mix a smaller batch, consider that, if you run out towards the end, it might be hard to mix a new small batch that matches in colour perfectly.

Start by mixing the base. Check carefully the instructions for your resin. If, for instance, your resin is meant to be mixed in a ratio of 4:1 by weight, that would mean 80g resin and 20g hardener. Pour both in a disposable plastic cup and mix well with a disposable wooden or plastic stick.
Page 14/21

TD-FBUH01A User Manual

I like the Berlin Uhr face to have coloured filling of the wells, which closely resembles the original where, even when the lamps were off, the colour of the glass could be seen. It’s up to your taste how you want your clock to look but, in my opinion, leaving the resin transparent doesn’t work well as you see straight down to the PCB and the LEDs. Also the light won’t be diffused.

For the resin not to be transparent you will need to add white dye to it. You can then decide to fill all wells with white or to further mix in yellow and red (my favourite option). With all these options, and variability of dyes, it’s absolutely necessary that you first do some tests with smaller batches and let them harden on a test surface. Once you are happy with the tint and milkiness of the resin, mix the full batch following the same recipe.

With the products I used I started from the yellow using, for a 100g resin batch, 20 drops of yellow and 30 of white. You can start from fewer drops, mix and pour a small amount on a disposable surface to get a better feeling of the actual colour and milkiness.

Once you are ready to start the pour place the assembled clock face on a surface where it can be perfectly flat and where you can leave it for at least 24h untouched. I found it useful to build a temporary support out of scrap wood and hot glue, as seen below.

Page 15/21

TD-FBUH01A User Manual

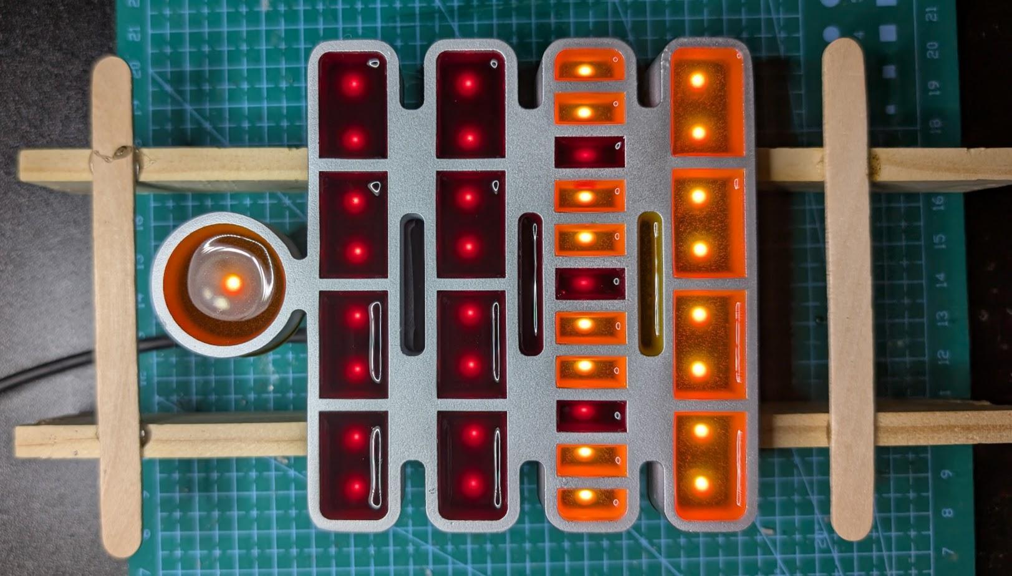
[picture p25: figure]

Familiarise yourself with a picture of the Berlin Uhr and make sure you know which wells are red and which yellow! Best of all you should power the clock, set it in test mode with all the lights on, and use them as a colour guide.

Load a large syringe with part of the resin. Always wipe the syringe outer surface completely clean with a piece of paper towel when you load it so you don’t have drippings on the clock face.

Start the pour from the large circular well at the top. This will give you a good indication of how flat the face is positioned. If you notice the level of the resin is higher on one side, prop gently the support by adding some thin cardboard or wood stick on the correct side until the resin sits completely flat.

Page 16/21

TD-FBUH01A User Manual

Start to pour the resin EXTREMELY SLOWLY, almost a drop at the time. Due to the high viscosity of the resin, if you put too much pressure the plunger will give way suddenly and spill out a large amount of resin. If this happens and resin goes where it shouldn’t, don’t panic. Suck back with the syringe as much of the spill as you can then proceed to clean all surfaces that got stained with paper towel and q-tips. Remember resin takes 24h to harden, so in the first hour or two you can still clean off pretty much any spilling. If some yellow has poured into a well that should be red make sure you clean extremely well the whole well down to the bottom with a q-tip otherwise when you pour the red some yellow streaks might appear. Make a note also of the wells where this happened and, when you proceed pouring the red, pour first only half and mix well with a stick to prevent streaks.

As you pour drop by drop, notice how the surface of the resin is concave. This meniscus is formed due to the viscosity of the resin. If you like the effect you might want to try to pour all wells to such a level where the meniscus is of the same depth. Personally, I prefer to keep pouring (tiny drops!) until the meniscus disappears and the surface is completely flat. Be careful at this stage you can afford only an extra drop or two before the resin starts to overflow.

Once you are done with the yellow double (triple!) check all yellow wells are filled and that you are satisfied with the level and the uniformity of the pour. If you notice any bubbles in the resin you can pop them by inserting and gently moving a needle in the bubble.

Start now to add red to the same resin, a few drops at the time and repeat the test on a disposable surface until you are satisfied with the colour. Red is overpowering yellow easily, so you can minimise the waste. With the dye I used I had to add 30 drops of red and 15 more of white to achieve a colour I liked. Use the same technique and a lot of patience as before to fill all the red wells.

| Page 17/21

TD-FBUH01A User Manual

Page 18/21

TD-FBUH01A User Manual

# Advanced

Your clock comes with a UART that you can use to send commands to it via a terminal program. This is not only an alternative way to set time, it’s also a way to change the clock colours. See the TD-M5037 User Manual for details on how to connect, send commands and alter register values.

## Registers Map

0x00 - 0x3F Movement Registers | See TD-M5037 User Manual for usage.
| 0x40 - 0x42 | Colour for LEDs that are “off”. This can be used to have the wells that are off still glow, perhaps with a very faint colour. | Default is 0x000000 (black)
| 0x43 - 0x45 | Colour for LEDs that are red in the original Berlin Uhr colour scheme (hours and every 3rd in the first minutes row). | Default is 0x050000 (red)
| 0x46 - 0x48 | Colour for LEDs that are yellow in the original Berlin Uhr colour scheme (top round light, minutes). | Default is 0x050500 (yellow)
| 0x49 - 0x7F | Not used

0x40 - 0x7F
Face Registers

Page 19/21

TD-FBUH01A User Manual

Page 20/21

TD-FBUH01A User Manual

# Appendix A - HW Revisions

REV.A | First version.

Page 21/21

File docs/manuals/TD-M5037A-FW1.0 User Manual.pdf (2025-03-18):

# TD-M5037A-FW1.0


# User Manual

TD-M5037A-FW1.0 User Manual

Page 2/27

TD-M5037A-FW1.0 User Manual

Page 3/27

TD-M5037A-FW1.0 User Manual

Page 4/27

TD-M5037A-FW1.0 User Manual

# General

## Features

The Tokei Digital TD-M5037 is a general purpose clock module that can be used as the base for designing clocks with different faces. It provides a RTC, with a backup battery, that can keep track of the current date and time even when the clock is not powered.

The module has a UART interface, allowing the user to set the time via a command interface and to tweak the configuration of both the module and the clock face.

Additionally the module provides several GPIO pins to both control a clock face and receive input from buttons placed on the clock face. These buttons allow the user to set the time in a more traditional way.

The module can also automatically switch to DST and back (EU rules only in FW1.0, for other territories DST can be set manually through the UART or simply ignored and time adjusted manually on the change date).

If you purchased the TD-M5037A as a kit to assemble see the “Assembling the Board” chapter for assembly instructions.

Page 5/27

TD-M5037A-FW1.0 User Manual

## Connections

Two female pin headers, protruding on the top side (opposite the battery) provide the mating interface to the clock face. The headers have 5 and 6 pins respectively to serve as a guide for the correct orientation of the module when plugging it on the face. These pins provide power to the clock face, digital data to control it, and bring into the module the lines from the three A,B,C buttons.

The choice to have the buttons on the clock face instead of the module was made to provide more flexibility in the design of the final clock, leaving freedom on the placement of the buttons on the face. In the same way, the power input to this module is made of two large pads where to solder the power supply. This allows for greater flexibility in the placement of eventual battery holders or external power connectors. An onboard USB connector would have instead limited the options and, depending on the clock face shape and orientation, could have resulted in the USB connector sitting in a non suitable location.

One the side opposite the headers is a holder for a CR2032 battery. If the battery is not installed time will be lost every time the power is lost. It’s strongly recommended to use a backup battery, however normal operation is possible without.

On the same side is also an ICSP (In Circuit Serial Programmer) interface that allows to flash a new version of the firmware or to flash an Arduino bootloader. If you received the module as part of a clock kit the firmware has already been flashed with the correct one for the face you selected and you will not need this interface.

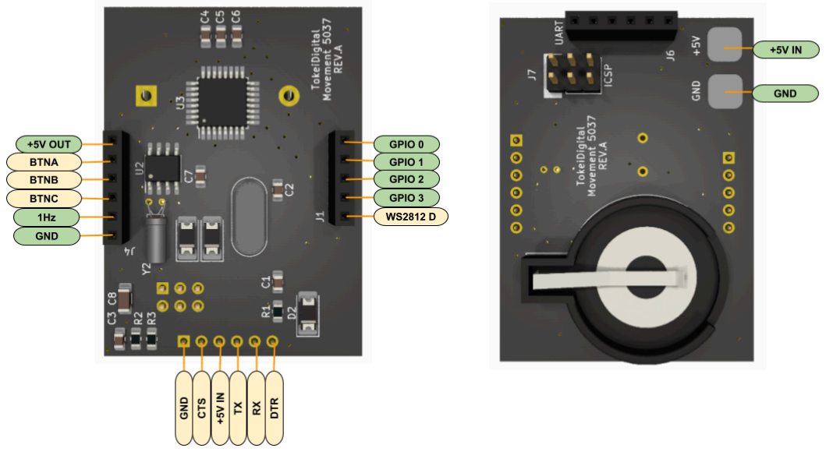
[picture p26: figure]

The table below details all the pins and their function.

+5V OUT | Power supply output for the clock face. Max available current for the face is 100mA. | CTS/TX/RX/DT R | UART interface. Allows to configure the clock through a serial interface. Also, if the module is flashed with the Arduino bootloader, sketches can be uploaded through this interface.
BTNA,B,C | Input pins for Buttons A,B,C. The module has internal pull-ups and expects the buttons to be pulling towards ground when pressed. These buttons allow you to do things like setting the date/time. | GPIO0,1,2,3 | General input/output pins that can be used by the clock face.
1Hz | 1Hz Square Wave output. This is an open collector output. | WS2812D | Dedicated output pin for clocks using WS2812 LEDs. If your clock face doesn’t use such LEDs this pin can be used as general IO.
GND | Common ground connection for power to the clock face. | +5V IN | Power Supply pad. There is polarity protection on board but no voltage protection. Ensure your power supply is stable and doesn’t exceed 5V. It needs to be able to supply enough current for the clock face (the movement consumption is few mA only).

## Setting Date and Time

Time set mode is entered with a long press on the A button. The first settable value (usually the hours) will start to flash on the clock face. Usually the clock will also indicate in some other way that it entered the time set mode, for instance flashing an LED or changing its color. For details see your specific clock face user manual.

NOTE: depending on how your clock displays time if the current value being set is zero you might not see anything flashing (e.g. in a binary clock). Press B or C once so the value is increased/decreased.

Once time set mode is entered use B and C to increase/decrease the value being set respectively. To move to the next value (e.g. minutes) just press once A. Depending on the abilities of your clock, you will cycle through all the values that can be set and return to the hours.

Once you are done setting the time, long press again A to exit time set mode.

Hint: to achieve a second-accurate setting, set the clock to the next minute. Then wait in time set mode until your reference clock shows :59 seconds, only at this point long press on A to exit time set mode. This works because, upon exciting time set mode, the clock always starts from second :00.

## Display Test Mode

It’s possible to enter test mode for your clock by long pressing on the C button. In this mode your clock will light all LEDs regardless of current time. This can be useful to ensure all LEDs are functioning and to test your power supply and ensure it can provide enough current. Long press again C to exit test mode.

# Assembling the Board

## Packing List

Before proceeding with the assembly of the components on the board, double check the packing list to make sure you have received all components and that everything is in good order.

Bag | Content
A | 2 x 22p (0805)
B | 5 x 100nF (0805)
C | 1 x 10uF (1206)
D | 1 x 1N5817 (2010)
E | 3 x 10K (0805)
F | 1 x ATmega328 (QFP-32) 1 x DS1307 (SOIC-8)
G | 1 x 16MHz Crystal 1 x 32.768KHz Crystal 1 x CR3032 Holder 1 x Pin 1x5 Vertical Female 1 x Pin 1x6 Vertical Female
| 1 x PCB TD-M5037A REV.A

## Top Assembly

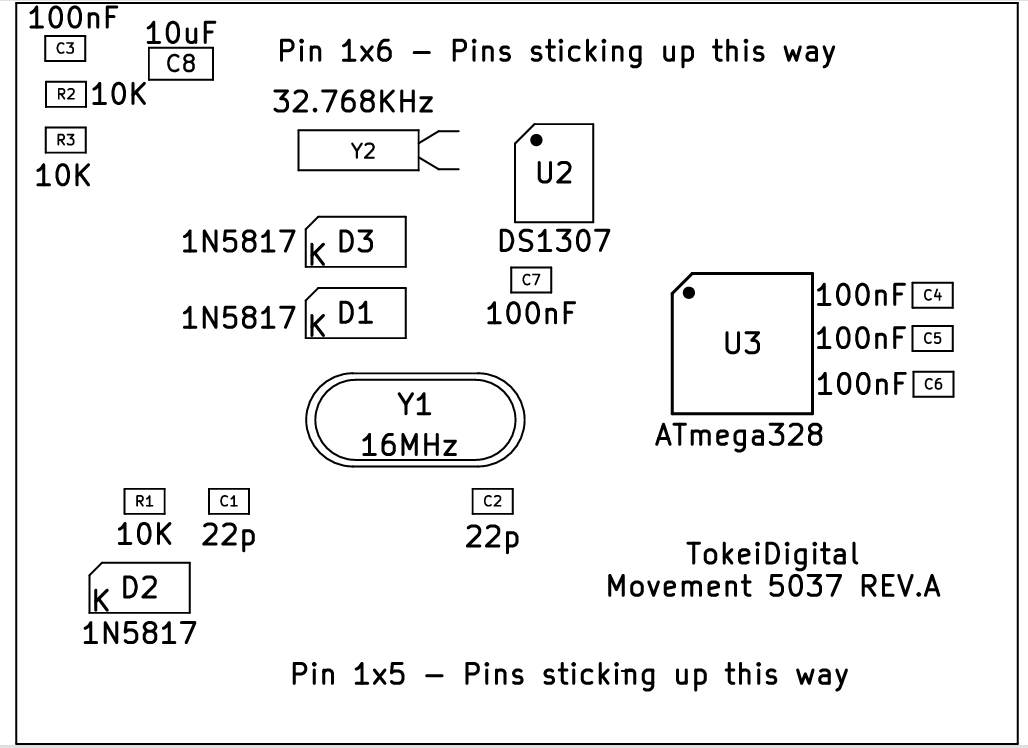
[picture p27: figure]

All components, with the exception of the battery holder, are assembled on the top part of the board. Depending on the tools you have available and your preference, you can use solder paste and position all the SMDs first to then reflow the board or just assemble the SMDs by hand. If you choose to assemble by hand make sure you have a very fine solder tip and very fine (0.2mm) tin. Pay attention to the orientation of diodes (the K marking on the image above corresponds to the grey band on the body of the component). Also the two chips need to be aligned with the dot on the body matching the image above. Assemble the crystals nex and, finally, solder the pin headers on this same side of the board.

## Bottom Assembly

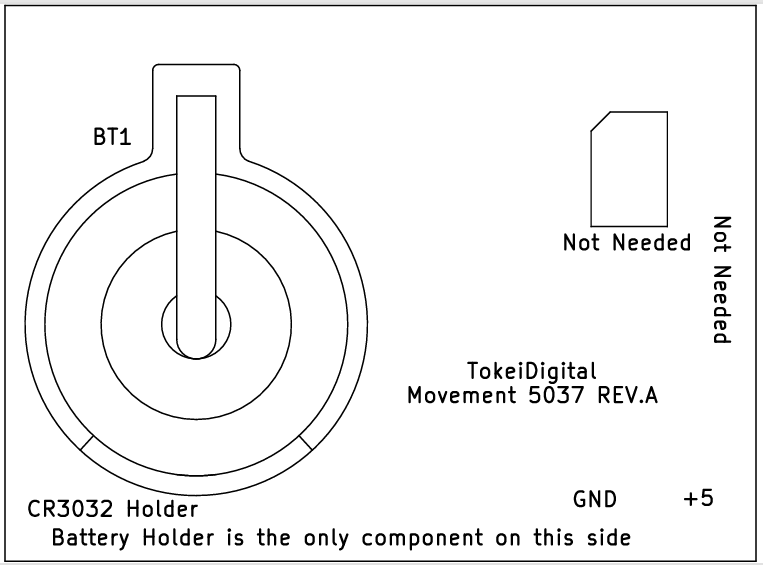
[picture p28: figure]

Flip the board and install the battery holder. For clock operation no other components are needed. If you are planning to use the UART you can install a 6 pin header on the pads labelled UART on the board. The choice of the type of pin header (male/female, 90 degrees etc.) depends on the type of USB-UART adapter board you have, whether you plan to encase the clock or not. The square pin next to the “UART” text is GND.

Also the ICSP connector (2x3 pins) is not needed unless you want to replace the firmware of the module, for instance to flash your own code for the clock face, an Arduino bootloader or an updated version of the firmware. Again, the type of pins depends on your programmer cable, though usually these are male pins.

Finally a power source needs to be soldered to the GND and +5 pads. Once more, the type of cable, battery holder or perhaps USB connector adapter board depends on how you plan to display and eventually encase your clock. For this reason the board was not designed with a USB onboard connector but just with the pads.

# Advanced

## UART

The module exposes a UART interface that allows the user to configure the module, including setting time, DST and, depending on the clock face, color of the LEDs and other face features.

## Physical Interface

The only pins needed to control the UART are TX, RX, and GND. The other standard serial port lines are used only by the Arduino bootloader if you choose to flash it.

The UART operates at 9600 BAUD, 8 bits, 1 stop bit (no parity).

The terminal should be configured for CR+LF line ending.

## Commands

Press enter once you connect to get a list of all the available commands and a banner reporting the current hardware and firmware versions. If you don’t receive any response, double check the connections and make sure the serial port parameters are set correctly.

TOKEI DIGITAL MOVEMENT 5037
VER: V1.0
FACE DRIVER: BUHR
H | HELP
N | PRINT NOW
R [START] [END] DUMP REGISTERS
S [START] | SET REGISTERS
T H:M WD D-M-Y | SET DATE/TIME
X | EXIT
OK

When you connect you might start to receive a burst of messages every second. These report the current date/time and other information. They can be set on/off by setting the relevant register (see next section). If the messages are coming they will stop once you press enter and will not resume until you exit interactive mode by giving the “X” command.

Print Current Time (N)
Send the “N” (now) command and press enter. The module will respond with the current date and time:

19:14 2 11-02-25
OK

The string is in the format:

HH:MM dayOfWeek day-month-year

Day of week is 1-7, with 1 indicating Monday.

Set Current Time (T)
Send the “T” (time) command followed by a space and the date and time you want to set. Use the same format returned by the N command.

T 19:14 2 11-02-25
OK

Dump Registers (R)
Send the “R” (read registers) command and press enter. The module will respond with a dump of all registers. Optionally you can specify a start and end (hex values) to limit the output.

R 0B 14
0008 | 00.00.00.00.00
0010 00.00.00.00.00.
OK

R
0000 00.00.00.01.00.00.00.00 0008 00.00.00.00.00.00.00.00 0010 00.00.00.00.00.00.00.00 0018 00.00.00.00.00.00.00.00 0020 00.00.00.00.00.00.00.00 0028 00.00.00.00.00.00.00.00 0030 00.00.00.00.00.00.00.00 0038 00.00.00.00.00.00.00.00 0040 00.00.00.05.00.00.05.05 0048 00.04.02.00.00.00.05.05 0050 00.05.02.04.04.01.06.02 0058 01.05.00.02.02.02.30.30 0060 30.00.00.00.00.00.00.00 0068 00.00.00.00.00.00.00.00 0070 00.00.00.00.00.00.00.00
0078 00.00.00.00.00.00.00.00
OK

For the meaning of each register see the next section which details the movement registers. See also your clock guide for face specific registers.

Set Registers (S)
Send the “S” (set registers) command followed by a space and the address (hexadecimal) of the first register you want to set. This command is interactive and will print the address and current value of the register.
You can now enter a new value, in hexadecimal and press enter. If you don’t want to change that register value you can just press enter to move to the next. Once you are done editing press X and enter to exit the command.

S 7B
007B 00 .
007C 01 .01
007D 02 .02
007E 00 .X
OK

Exit Interactive Mode (X)
Once you are done you can send the X command and press enter to exit the interactive mode. If the serial output is enabled (see register 0x03) the notifications will resume.

## Registers Map

0x00 - 0x3F Movement Registers | 0x00 | DST. | 0=AUTO, 1=OFF, 2=ON
| 0x01 | Reserved for future use.
| 0x02 | Reserved for future use.
| 0x03 | Serial output protocol. | 0=OFF, 1=V1
0x40 - 0x7F Face Registers | See face manual for usage.

0x00 If set to 0 DST AUTO is enabled and the clock will transition automatically in and out of summer time on the correct date. Currently the module supports the EU rules only. If you live in a different territory you can set manually DST on/off on the change date and the time will adjust. You can also leave DST OFF and change the time manually on the change day.

0x03 Controls the serial output protocol. When enabled (set to 1 for Version 1) the module will send out messages at one second interval. The messages continue indefinitely until you press enter, at that point they stop to allow usage of the interactive interface. The messages will resume exiting interactive mode with the X command. Messages look as follows:

$V1!INFO0,V1.0,DCF77
$V1!DATE,11-02-2025
$V1!TIME,19:37:29
$V1!DOW,2
$V1!DST,OFF,AUTO

Each message starts with $ followed by the protocol version. Following are comma separated tokens. The first indicating the message type and the others, in variable amount, are the parameters. Each message ends with a CR+LF.

$V1!INFO0 reports firmware version and face type.

$V1!DATE reports the current date in dd-mm-yyyy format.

$V1!TIME reports the current time in HH:MM:SS format.

$V1!DOW reports the current day of week. The value ranges from 1 to 7. Monday being 1.

$V1!DST reports the current DST status. The first parameter is either ON or OFF. The second parameter is present only if AUTO is enabled.

## Flashing the Arduino Bootloader

Whether you purchased the module on its own to design your own face, or you received it as part of a clock kit and you want to write your own firmware for it, you have the option to flash the Arduino bootloader on the board and use Arduino sketches.

NOTE: if you flash the Arduino bootloader it will override the clock firmware. For your clock to work you will need to write a sketch for it. Tokei Digital doesn’t provide Arduino sketches for its clocks. However you can also flash back the correct firmware, see next section for details.

If you are sure you want to flash the Arduino bootloader follow these simple steps:

- Connect an ICSP programmer (such as USPAsp) to the ICSP connector
- Open the Arduino IDE and configure the board as seen below (1). It’s important you choose ATMega328P 5V, 16MHz or things won’t work correctly.

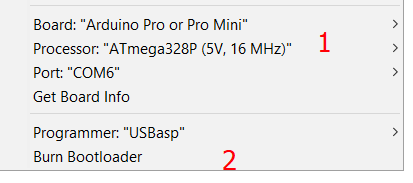
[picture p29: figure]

- Choose “Burn Bootloader” (2)
- Once the process ends disconnect the programmer
- Connect now the board with a USB UART as any other Arduino board
- Select the right COM port that gets assigned to your board
- Upload your first sketch!

Note: REV.A of the board has a 100nF capacitor labelled C4 that interferes with the reset circuitry of the Arduino (which uses the serial interface DTR line to reset the processor). Remove this capacitor if you want to flash the Arduino bootloader. Future revisions of the board will omit this component as, in fact, it’s not needed even in other configurations.

## Flashing the Firmware

If you purchased the module as part of a clock kit you do not need to flash the firmware as the ATMega was already flashed for you with the FW variant needed for your clock face. However, if you are planning to flash your own firmware, or restore the original one after flashing the Arduino bootloader follow these simple steps.
This assumes you have a USBAsp ICSP programmer and a working installation of avr-gcc.
- Connect the board to the ICSP programmer
- Clone the https://github.com/nicolacimmino/TokeiDigital repository
- Open a unix like shell (e.g. GitBash) or your terminal if you are running linux
- Run the interactive flash tool you can find under src/movement with sh flash.sh
- You will be presented with a dialog like below:


- Select the correct face and then press 9 to flash

If you have a different programmer have a look into the Makefile in the src/movement folder of the repo and adjust for your programmer.

# Appendix A - HW Revisions

REV.A | First version. Only known issue at the time of writing is C4 interfering with Arduino reset. You can safely remove C4.

# Appendix B - Schematic


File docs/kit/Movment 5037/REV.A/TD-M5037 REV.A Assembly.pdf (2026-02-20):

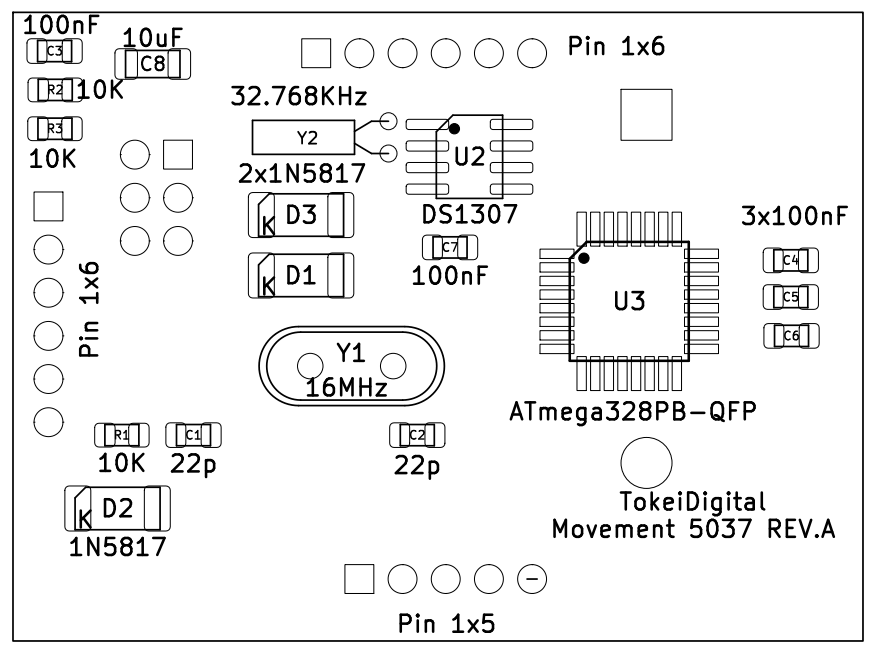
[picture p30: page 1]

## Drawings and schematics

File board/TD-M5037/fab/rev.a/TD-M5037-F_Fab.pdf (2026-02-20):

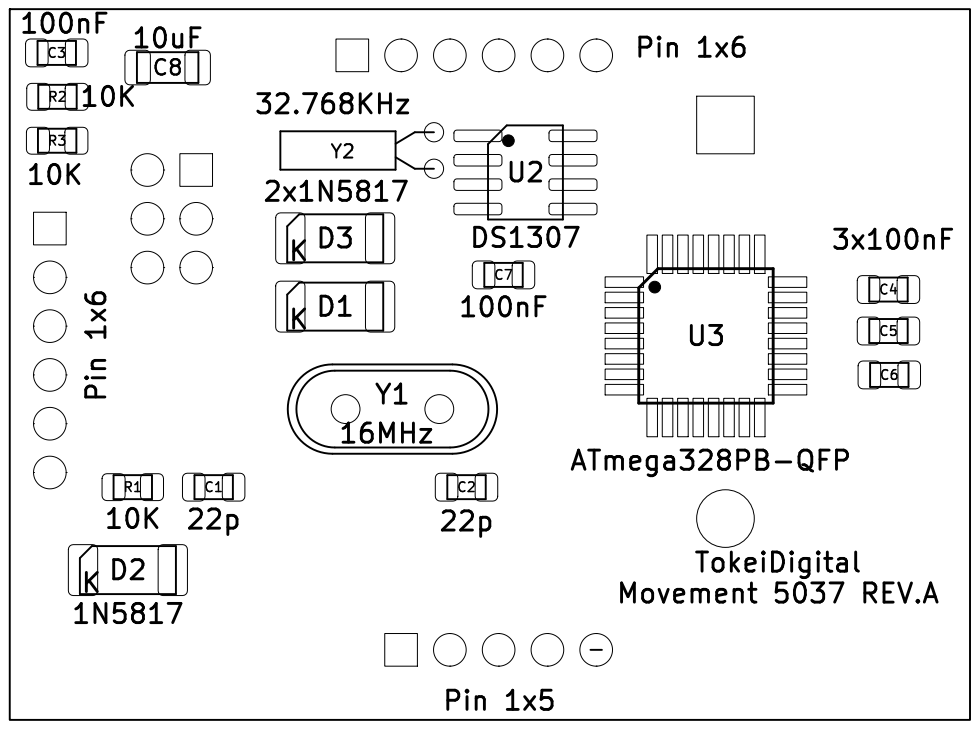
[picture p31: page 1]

Pin 1x6 TokeiDigital Movement 5037 REV.A

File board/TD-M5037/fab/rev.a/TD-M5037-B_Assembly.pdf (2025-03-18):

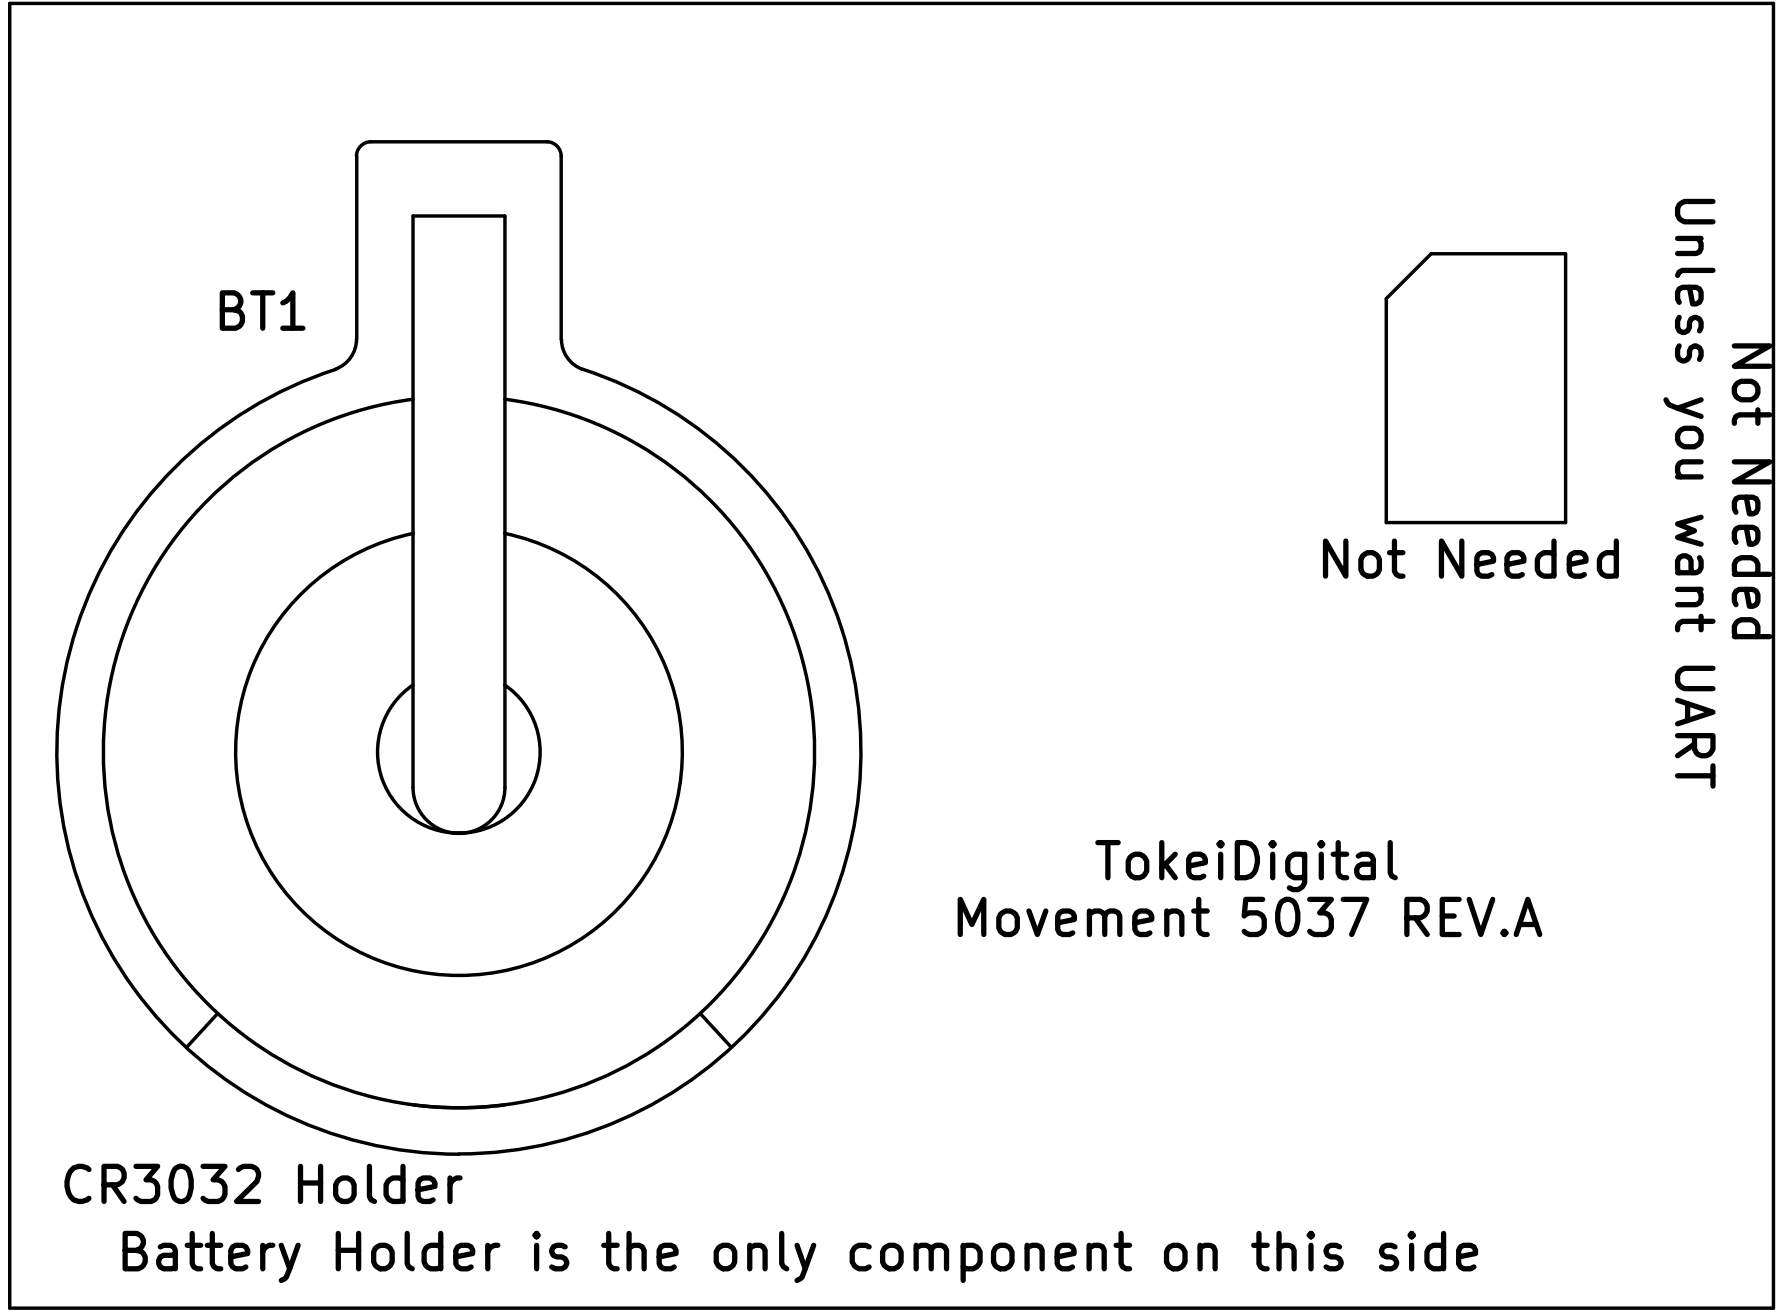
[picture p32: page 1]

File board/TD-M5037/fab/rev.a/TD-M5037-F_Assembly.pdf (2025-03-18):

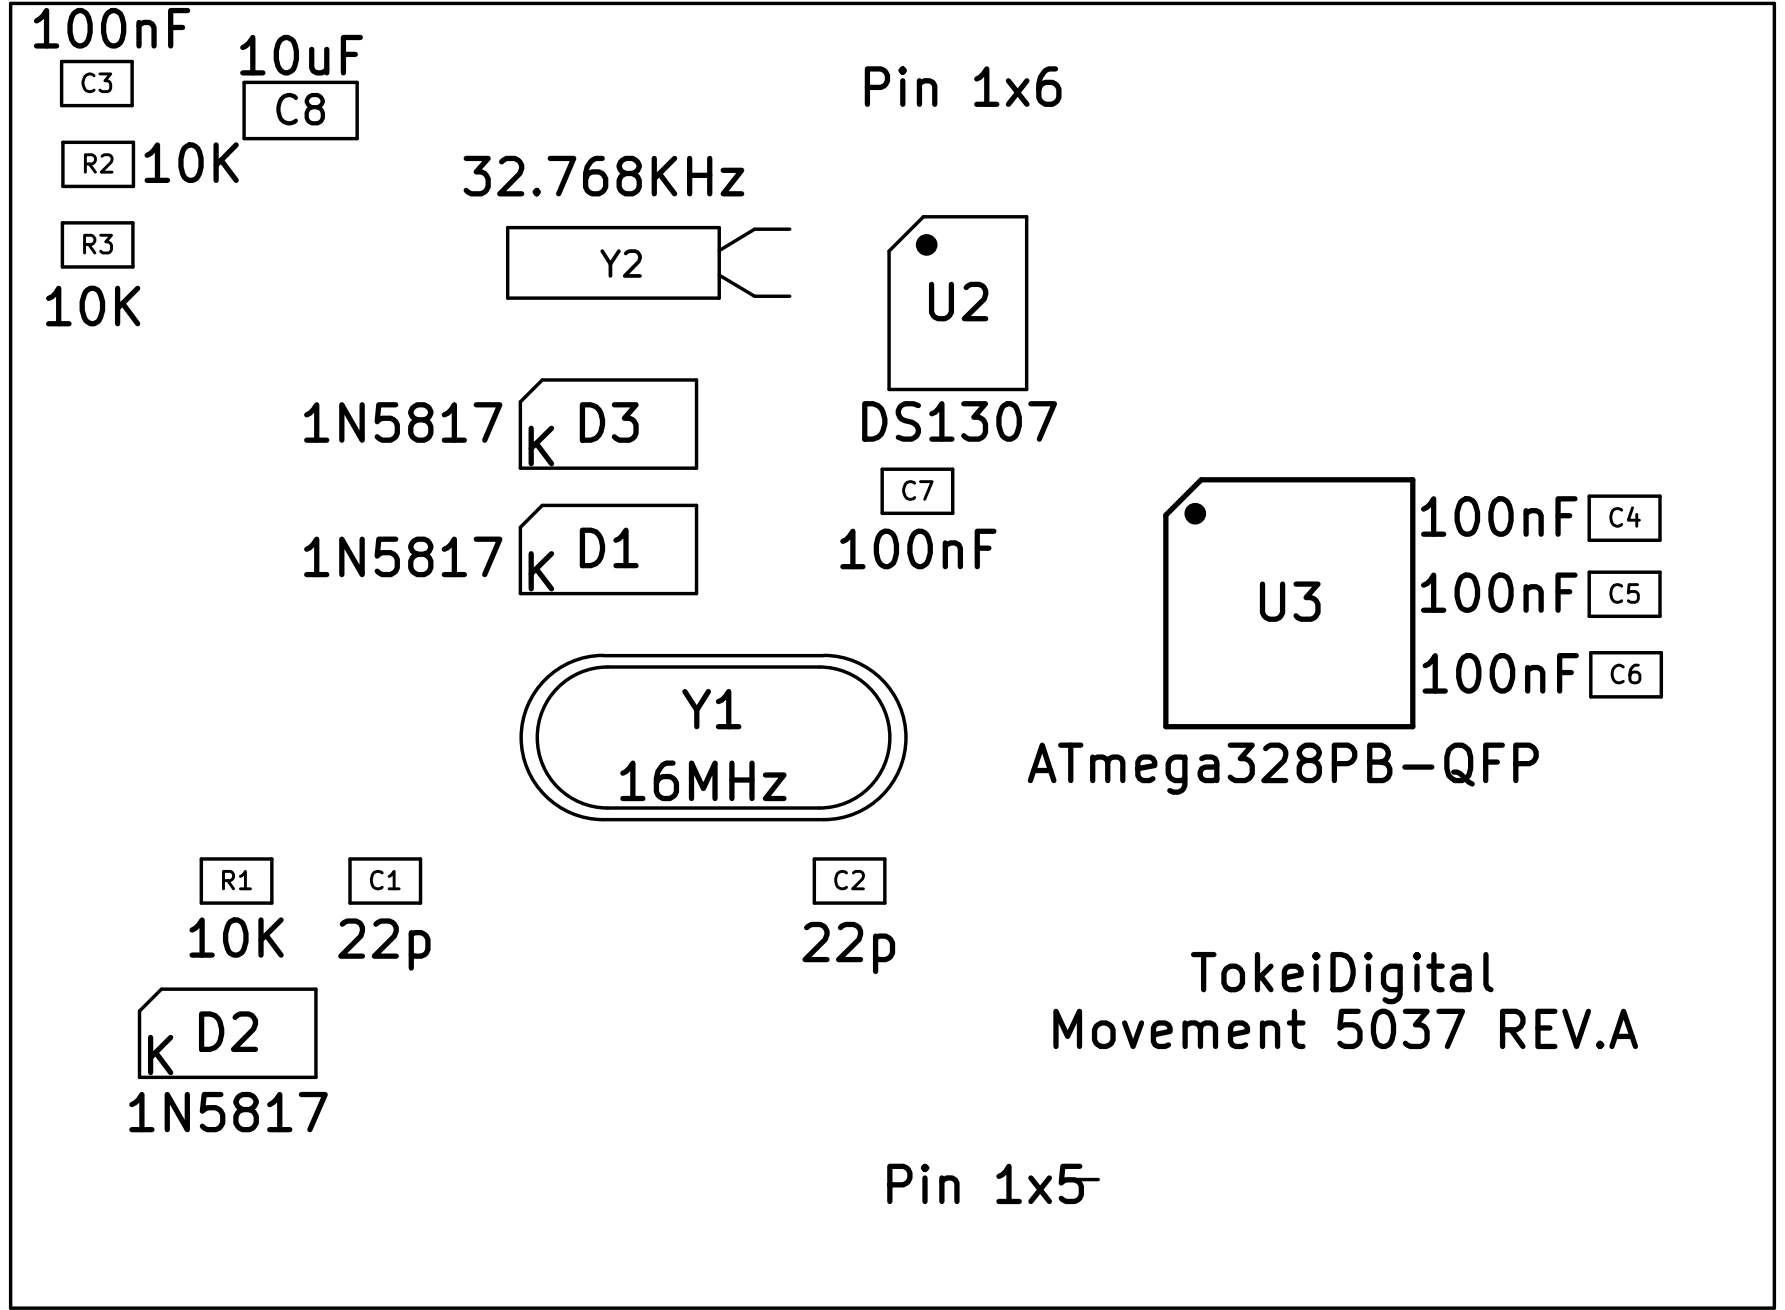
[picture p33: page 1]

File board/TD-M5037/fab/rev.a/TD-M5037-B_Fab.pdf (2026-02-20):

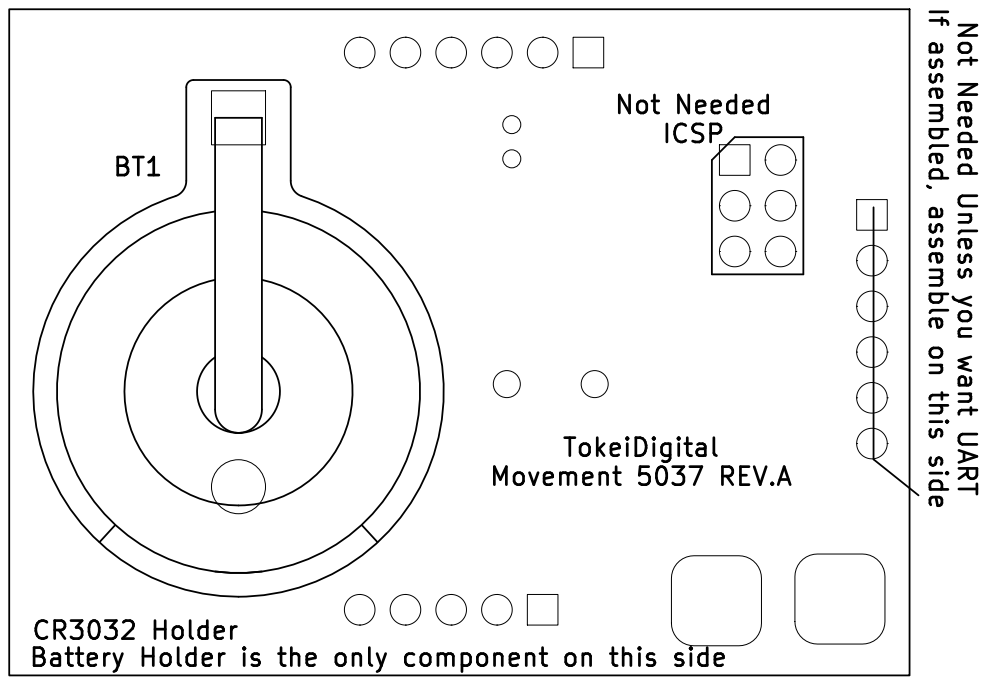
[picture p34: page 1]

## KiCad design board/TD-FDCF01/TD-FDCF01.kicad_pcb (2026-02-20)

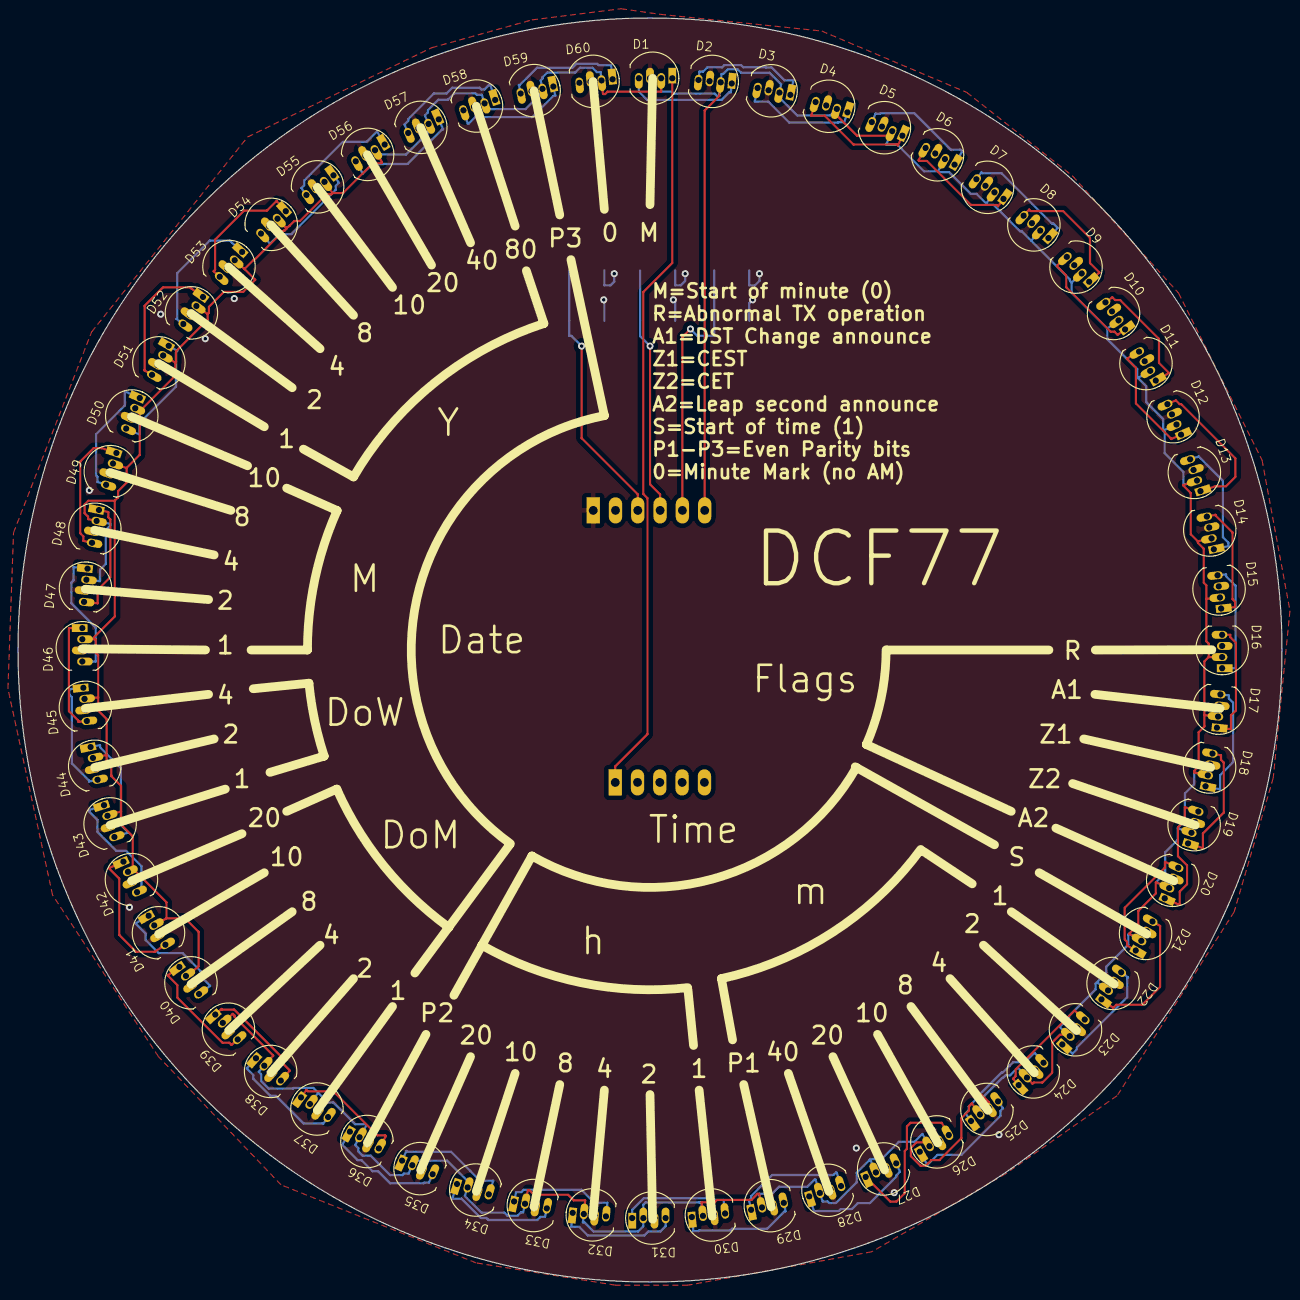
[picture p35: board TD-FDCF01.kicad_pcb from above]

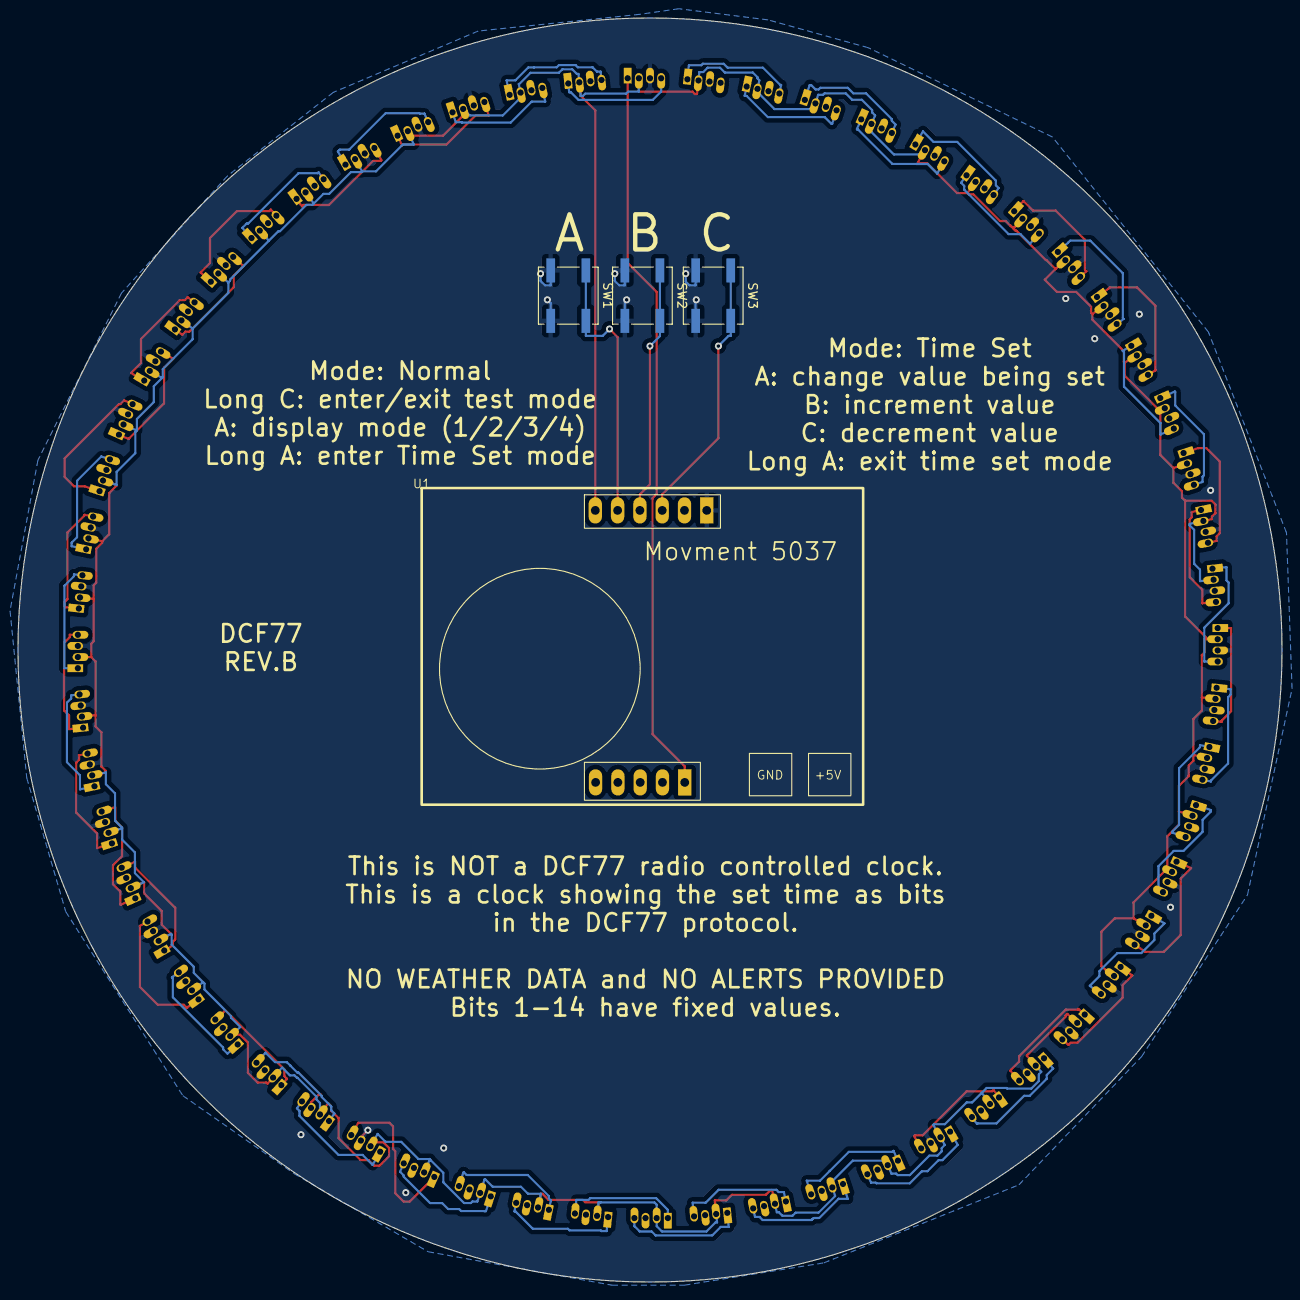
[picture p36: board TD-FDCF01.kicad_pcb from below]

Board: 2 copper layers, 144.0 x 144.0 mm, 64 parts (4 on the bottom side), 65 nets.

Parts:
D1, D2, D3, D4, D5, D6, D7, D8, D9, D10, D11, D12, D13, D14, D15, D16, D17, D18, D19, D20, D21, D22, D23, D24, D25, D26, D27, D28, D29, D30, D31, D32, D33, D34, D35, D36, D37, D38, D39, D40, D41, D42, D43, D44, D45, D46, D47, D48, D49, D50, D51, D52, D53, D54, D55, D56, D57, D58, D59, D60: WS2812-5MM
SW1, SW2, SW3: SW_Push; Tactile SW SMD
U1: Movement5037 TH

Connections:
+5V: D1.2 (Vcc), D2.2 (Vcc), D3.2 (Vcc), D4.2 (Vcc), D5.2 (Vcc), D6.2 (Vcc), D7.2 (Vcc), D8.2 (Vcc), D9.2 (Vcc), D10.2 (Vcc), D11.2 (Vcc), D12.2 (Vcc), D13.2 (Vcc), D14.2 (Vcc), D15.2 (Vcc), D16.2 (Vcc), D17.2 (Vcc), D18.2 (Vcc), D19.2 (Vcc), D20.2 (Vcc), D21.2 (Vcc), D22.2 (Vcc), D23.2 (Vcc), D24.2 (Vcc), D25.2 (Vcc), D26.2 (Vcc), D27.2 (Vcc), D28.2 (Vcc), D29.2 (Vcc), D30.2 (Vcc), D31.2 (Vcc), D32.2 (Vcc), D33.2 (Vcc), D34.2 (Vcc), D35.2 (Vcc), D36.2 (Vcc), D37.2 (Vcc), D38.2 (Vcc), D39.2 (Vcc), D40.2 (Vcc), D41.2 (Vcc), D42.2 (Vcc), D43.2 (Vcc), D44.2 (Vcc), D45.2 (Vcc), D46.2 (Vcc), D47.2 (Vcc), D48.2 (Vcc), D49.2 (Vcc), D50.2 (Vcc), D51.2 (Vcc), D52.2 (Vcc), D53.2 (Vcc), D54.2 (Vcc), D55.2 (Vcc), D56.2 (Vcc), D57.2 (Vcc), D58.2 (Vcc), D59.2 (Vcc), D60.2 (Vcc), U1.6 (+5)
/LEDD: D1.1 (DIn), U1.7 (WS2812D)
/LedA/LEDD_CONT: D30.4 (DOut), D31.1 (DIn)
GND: D1.3 (GND), D2.3 (GND), D3.3 (GND), D4.3 (GND), D5.3 (GND), D6.3 (GND), D7.3 (GND), D8.3 (GND), D9.3 (GND), D10.3 (GND), D11.3 (GND), D12.3 (GND), D13.3 (GND), D14.3 (GND), D15.3 (GND), D16.3 (GND), D17.3 (GND), D18.3 (GND), D19.3 (GND), D20.3 (GND), D21.3 (GND), D22.3 (GND), D23.3 (GND), D24.3 (GND), D25.3 (GND), D26.3 (GND), D27.3 (GND), D28.3 (GND), D29.3 (GND), D30.3 (GND), D31.3 (GND), D32.3 (GND), D33.3 (GND), D34.3 (GND), D35.3 (GND), D36.3 (GND), D37.3 (GND), D38.3 (GND), D39.3 (GND), D40.3 (GND), D41.3 (GND), D42.3 (GND), D43.3 (GND), D44.3 (GND), D45.3 (GND), D46.3 (GND), D47.3 (GND), D48.3 (GND), D49.3 (GND), D50.3 (GND), D51.3 (GND), D52.3 (GND), D53.3 (GND), D54.3 (GND), D55.3 (GND), D56.3 (GND), D57.3 (GND), D58.3 (GND), D59.3 (GND), D60.3 (GND), SW1.2, SW2.2, SW3.2, U1.1 (GND)
unnamed: D1.4 (DOut), D2.1 (DIn)
unnamed: D2.4 (DOut), D3.1 (DIn)
unnamed: D3.4 (DOut), D4.1 (DIn)
unnamed: D4.4 (DOut), D5.1 (DIn)
unnamed: D5.4 (DOut), D6.1 (DIn)
unnamed: D6.4 (DOut), D7.1 (DIn)
unnamed: D7.4 (DOut), D8.1 (DIn)
unnamed: D8.4 (DOut), D9.1 (DIn)
unnamed: D9.4 (DOut), D10.1 (DIn)
unnamed: D10.4 (DOut), D11.1 (DIn)
unnamed: D11.4 (DOut), D12.1 (DIn)
unnamed: D12.4 (DOut), D13.1 (DIn)
unnamed: D13.4 (DOut), D14.1 (DIn)
unnamed: D14.4 (DOut), D15.1 (DIn)
unnamed: D15.4 (DOut), D16.1 (DIn)
unnamed: D16.4 (DOut), D17.1 (DIn)
unnamed: D17.4 (DOut), D18.1 (DIn)
unnamed: D18.4 (DOut), D19.1 (DIn)
unnamed: D19.4 (DOut), D20.1 (DIn)
unnamed: D20.4 (DOut), D21.1 (DIn)
unnamed: D21.4 (DOut), D22.1 (DIn)
unnamed: D22.4 (DOut), D23.1 (DIn)
unnamed: D23.4 (DOut), D24.1 (DIn)
unnamed: D24.4 (DOut), D25.1 (DIn)
unnamed: D25.4 (DOut), D26.1 (DIn)
unnamed: D26.4 (DOut), D27.1 (DIn)
unnamed: D27.4 (DOut), D28.1 (DIn)
unnamed: D28.4 (DOut), D29.1 (DIn)
unnamed: D29.4 (DOut), D30.1 (DIn)
unnamed: D31.4 (DOut), D32.1 (DIn)
unnamed: D32.4 (DOut), D33.1 (DIn)
unnamed: D33.4 (DOut), D34.1 (DIn)
unnamed: D34.4 (DOut), D35.1 (DIn)
unnamed: D35.4 (DOut), D36.1 (DIn)
unnamed: D36.4 (DOut), D37.1 (DIn)
unnamed: D37.4 (DOut), D38.1 (DIn)
unnamed: D38.4 (DOut), D39.1 (DIn)
unnamed: D39.4 (DOut), D40.1 (DIn)
unnamed: D40.4 (DOut), D41.1 (DIn)
unnamed: D41.4 (DOut), D42.1 (DIn)
unnamed: D42.4 (DOut), D43.1 (DIn)
unnamed: D43.4 (DOut), D44.1 (DIn)
unnamed: D44.4 (DOut), D45.1 (DIn)
unnamed: D45.4 (DOut), D46.1 (DIn)
unnamed: D46.4 (DOut), D47.1 (DIn)
unnamed: D47.4 (DOut), D48.1 (DIn)
unnamed: D48.4 (DOut), D49.1 (DIn)
unnamed: D49.4 (DOut), D50.1 (DIn)
unnamed: D50.4 (DOut), D51.1 (DIn)
unnamed: D51.4 (DOut), D52.1 (DIn)
unnamed: D52.4 (DOut), D53.1 (DIn)
unnamed: D53.4 (DOut), D54.1 (DIn)
unnamed: D54.4 (DOut), D55.1 (DIn)
unnamed: D55.4 (DOut), D56.1 (DIn)
unnamed: D56.4 (DOut), D57.1 (DIn)
unnamed: D57.4 (DOut), D58.1 (DIn)
unnamed: D58.4 (DOut), D59.1 (DIn)
unnamed: D59.4 (DOut), D60.1 (DIn)
unnamed: SW1.1, U1.5 (BTNA)
unnamed: SW2.1, U1.4 (BTNB)
unnamed: SW3.1, U1.3 (BTNC)

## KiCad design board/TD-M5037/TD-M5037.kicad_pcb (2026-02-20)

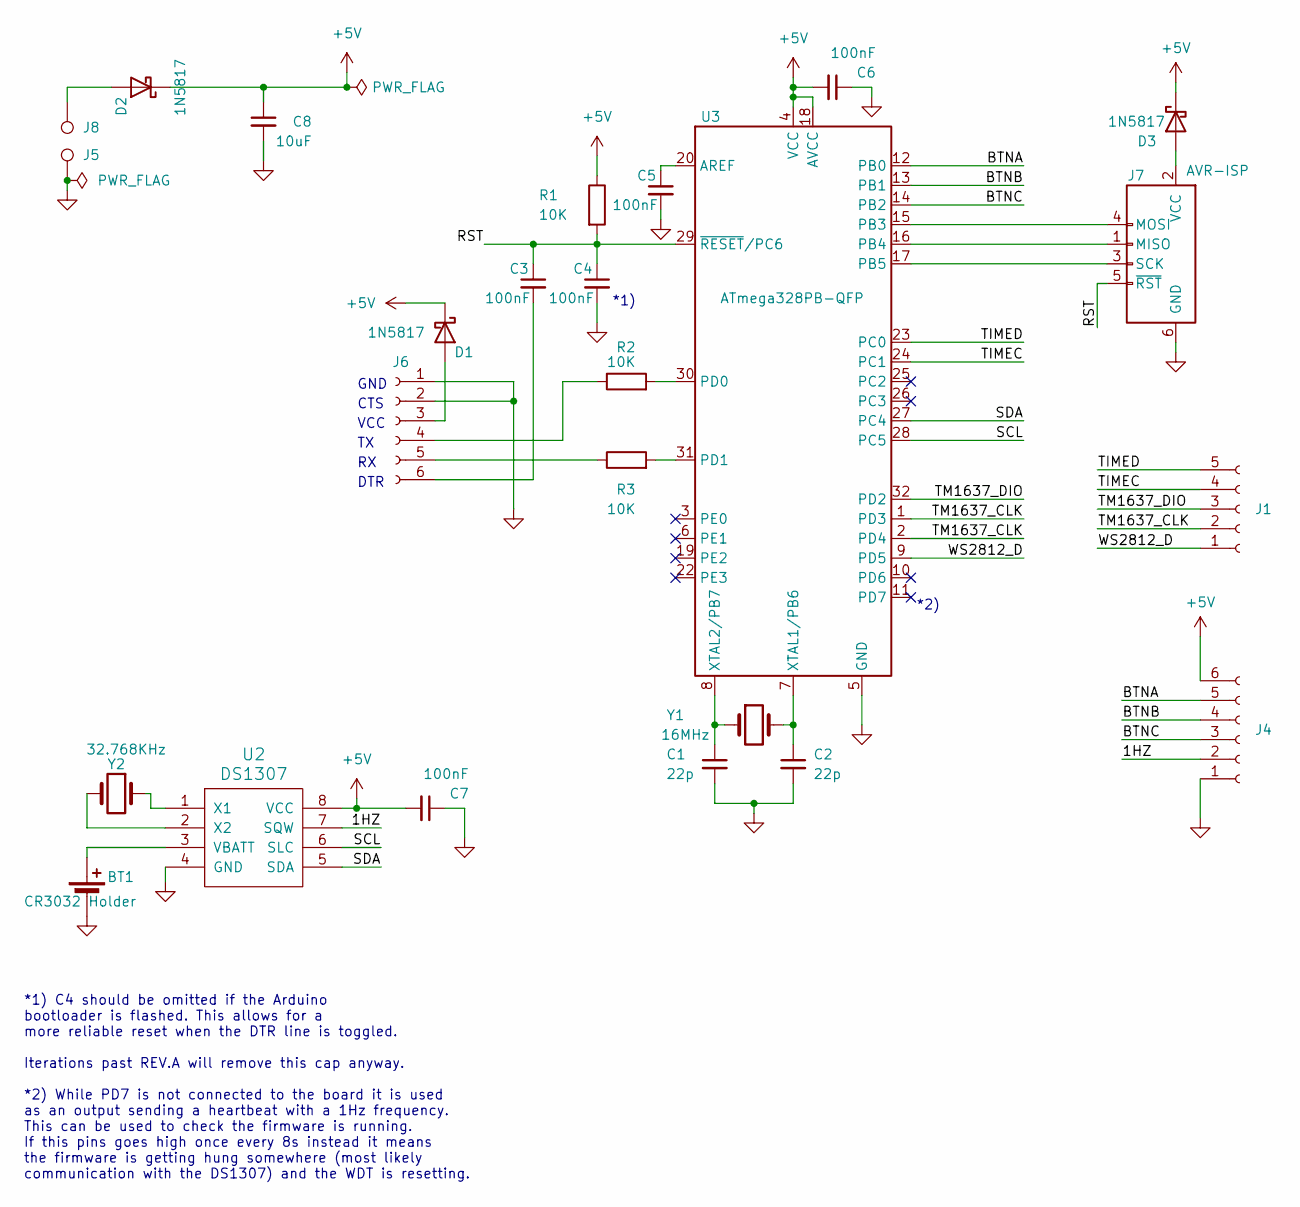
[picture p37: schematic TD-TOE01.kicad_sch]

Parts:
BT1: CR3032 Holder; CR2032 Holder
C1, C2: 22p; C_0805
C3, C4, C5, C6, C7: 100nF; C_0805
C8: 10uF; C_1206
D1, D2, D3: 1N5817; D_2010
J1: Pin 1x5; PIN 1x05
J4, J6: Pin 1x6; PIN 1x06
J5, J8: PowerPad; Power Pin
J7: AVR-ISP; PIN 2x03
R1, R2, R3: 10K; R_0805
U2: DS1307; SOIC-8
U3: ATmega328PB-QFP; TQFP-32
Y1: 16MHz; Crystal Vertical
Y2: 32.768KHz; Crystal Horizontal

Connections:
+5V: C6.2, C7.2, C8.1, D1.1 (K), D2.1 (K), D3.1 (K), J4.6, R1.1, U2.8 (VCC), U3.4 (VCC), U3.18 (AVCC)
/1HZ: J4.2, U2.7 (SQW)
/BTNA: J4.5, U3.12 (PB0)
/BTNB: J4.4, U3.13 (PB1)
/BTNC: J4.3, U3.14 (PB2)
/RST: C3.1, C4.1, J7.5 (~RST), R1.2, U3.29 (~RESET/PC6)
/SCL: U2.6 (SLC), U3.28 (PC5)
/SDA: U2.5 (SDA), U3.27 (PC4)
/TIMEC: J1.4, U3.24 (PC1)
/TIMED: J1.5, U3.23 (PC0)
/TM1637_CLK: J1.2, U3.1 (PD3), U3.2 (PD4)
/TM1637_DIO: J1.3, U3.32 (PD2)
/WS2812_D: J1.1, U3.9 (PD5)
GND: BT1.2 (-), C1.2, C2.2, C4.2, C5.2, C6.1, C7.1, C8.2, J4.1, J5.1, J6.1, J6.2, J7.6 (GND), U2.4 (GND), U3.5 (GND), U3.21 (GND)
unnamed: BT1.1 (+), U2.3 (VBATT)
unnamed: D1.2 (A), J6.3
unnamed: D2.2 (A), J8.1
unnamed: D3.2 (A), J7.2 (VCC)
unnamed: J6.4, R2.1
unnamed: J6.5, R3.1
unnamed: C3.2, J6.6
unnamed: J7.1 (MISO), U3.16 (PB4)
unnamed: J7.4 (MOSI), U3.15 (PB3)
unnamed: J7.3 (SCK), U3.17 (PB5)
unnamed: U2.1 (X1), Y2.1
unnamed: U2.2 (X2), Y2.2
unnamed: C5.1, U3.20 (AREF)
unnamed: R2.2, U3.30 (PD0)
unnamed: R3.2, U3.31 (PD1)
unnamed: C2.1, U3.7 (XTAL1/PB6), Y1.2
unnamed: C1.1, U3.8 (XTAL2/PB7), Y1.1

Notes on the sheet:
*1) C4 should be omitted if the Arduino bootloader is flashed. This allows for a more reliable reset when the DTR line is toggled. Iterations past REV.A will remove this cap anyway. *2) While PD7 is not connected to the board it is used as an output sending a heartbeat with a 1Hz frequency. This ca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
*1)
DTR
GND
VCC
*2)
CTS

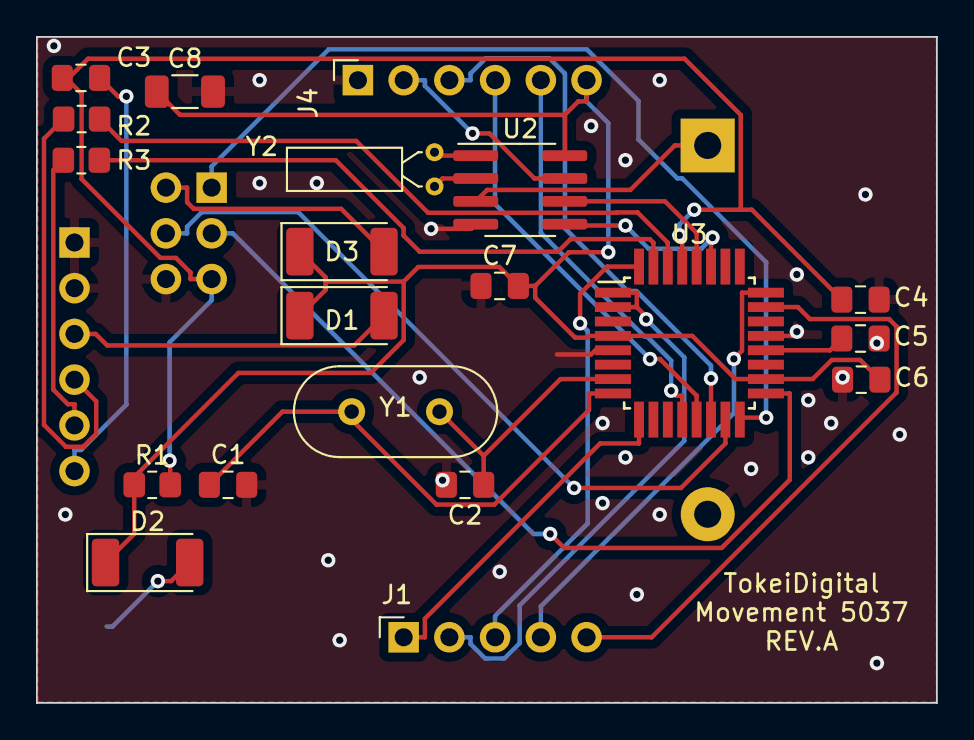
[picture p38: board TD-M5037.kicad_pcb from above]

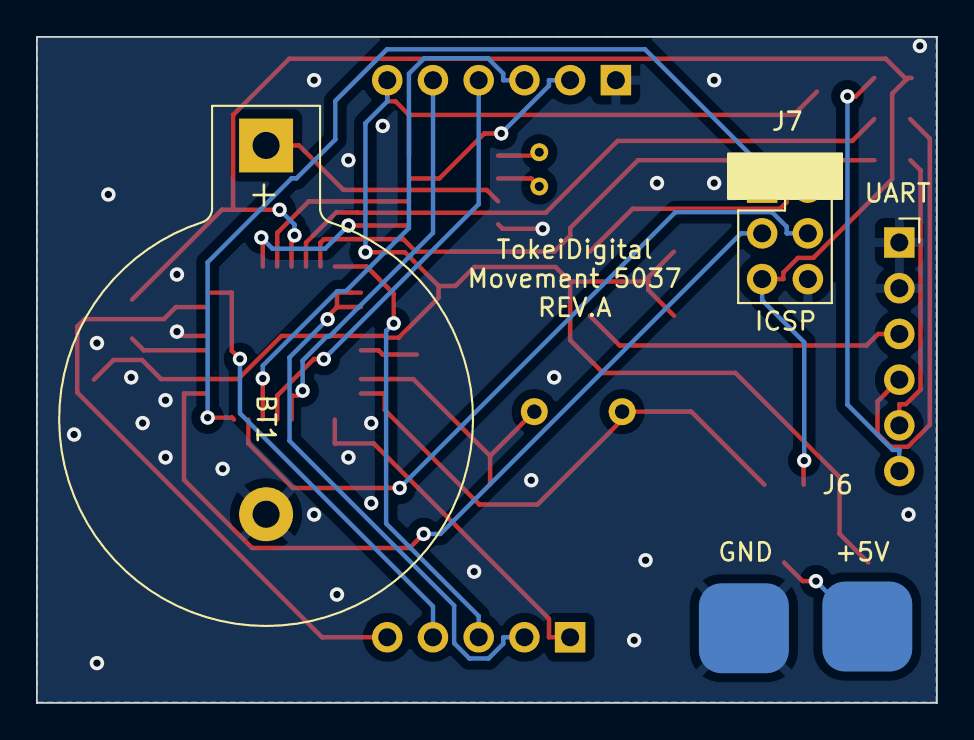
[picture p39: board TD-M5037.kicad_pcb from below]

Board: 2 copper layers, 50.0 x 37.0 mm, 25 parts (5 on the bottom side), 31 nets.

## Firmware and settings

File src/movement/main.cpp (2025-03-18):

/********************************************************************************************
 *
 *  Copyright (C) 2024 Nicola Cimmino
 *
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
 *
 *******************************************************************************************/

#include <stdbool.h>
#include <avr/io.h>
#include <avr/wdt.h>
#include "AMOS.h"
#include "faceDrivers/Face.h"
#include "DS1307.h"
#include "hardware.h"
#include "Button.h"
#include "Registers.h"
#include "SerialInterface.h"
#include "TimeSetter.h"
#include "Diagnostic.h"

void refreshFace()
{
    Face::showTime(DS1307::getDateTime());
}

int main(void)
{
    wdt_enable(WDTO_8S);
    
    AMOS::init();
    Diagnostic::init();
    
    SerialInterface::init();

    SerialInterface::printStartup();

    UTWI::init();
    Face::init();
    TimeSetter::init();

    AMOS::queueEveryMs(200, refreshFace);

    Button buttonA = Button(BTNA_PIN);
    Button buttonB = Button(BTNB_PIN);
    Button buttonC = Button(BTNC_PIN);

    // Just hit the DS1307 once before we confirm the
    //  boot was successful, if there's a communiction
    //  issue the WD will reset us and we get a change
    //  to re-initialize everything.
    DS1307::getDateTime();

    SerialInterface::printStartupDone();

    while (1)
    {
        AMOS::loop();

        buttonA.loop();
        buttonB.loop();
        buttonC.loop();

        wdt_reset();
    }
}

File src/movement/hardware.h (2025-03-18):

#ifndef __HARDWARE_H__
#define __HARDWARE_H__

#define BTNA_PIN 0
#define BTNB_PIN 1
#define BTNC_PIN 2

#endif

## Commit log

2025-03-22 Ship with DST off so faces with no date don't act erraticaly on date change unless user sets date with UART
2026-02-10 New DCF face cover proto
    [FaceDCF77_v3-Body.stl, FaceDCF77_v3.FCStd]
2026-02-13 Face tweaks
    [FaceDCF77_v2.FCStd, FaceDCF77_v3-Body.3mf, FaceDCF77_v3-Body.stl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]
2026-02-20 DCF LEDs radially, tweaks to silkscreen
    [TD-FDCF01-B_Cu.gbr, TD-FDCF01-B_Mask.gbr, TD-FDCF01-B_Paste.gbr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]
2026-02-20 Prepare for sale
    [FaceDCF77_v3-Body.stl, TD-M5037.kicad_pcb, TD-M5037.kicad_sch]
2026-03-06 Final sale prep
    [TD-FDCF01-B_Cu.gbr, TD-FDCF01-B_Mask.gbr, TD-FDCF01-B_Paste.gbr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]

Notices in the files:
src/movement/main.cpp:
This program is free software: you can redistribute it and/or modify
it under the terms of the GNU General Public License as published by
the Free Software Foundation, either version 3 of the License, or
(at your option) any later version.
